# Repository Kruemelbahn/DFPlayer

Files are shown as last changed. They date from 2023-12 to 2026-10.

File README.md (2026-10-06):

# DFPlayer

DFPlayer is an ATmega328-board to control a soundmodul "DFPlayer - mini".<br>
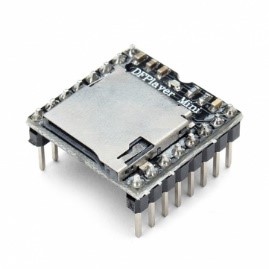
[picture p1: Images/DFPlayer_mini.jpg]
<br>

For more details please refer to the [manual](Documentation/AVRSound_DFPlayer.pdf).<br>

### Sound-FRED
There is also a hardware-version for a Sound-FRED available:<br>
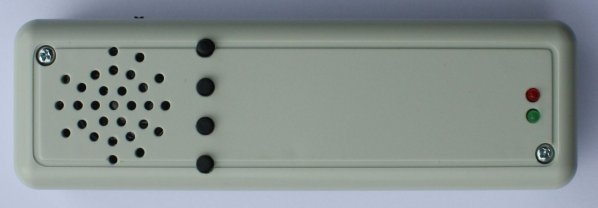
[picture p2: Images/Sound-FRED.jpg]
<br>
For compilation as Sound-FRED active/deactivate #defines in DFPlayer.ino and use this [boarddefinition](Boarddefinition%20for%20SoundFRED.txt).<br>

For more details please refer to the [manual](Documentation/AVRSound_DFPlayer-Sound-FRED.pdf).<br>

A battery tray for holding the battery can be found [here](https://github.com/Kruemelbahn/3D-Printables/blob/main/Geh%C3%A4use%20und%20Komponenten/Akkuschale-SoundFred.stl).

### Requested libraries
DFPlayer requires my libraries listed below in addition to various Arduino standard libraries:<br> 
- [HeartBeat](https://www.github.com/Kruemelbahn/HeartBeat)
- [OLEDPanel](https://www.github.com/Kruemelbahn/OLEDPanel)

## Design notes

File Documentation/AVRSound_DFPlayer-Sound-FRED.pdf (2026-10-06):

AVR-Sound – DFPlayer Sound-FRED | Version 22

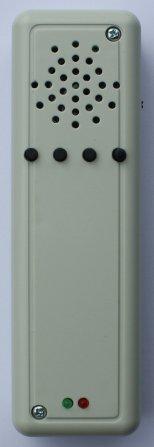
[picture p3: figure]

06.10.2026 | 1

Dipl.-Ing. Michael Zimmermann
Buchenstr. 15
42699 Solingen
- 0212 46267
- http://www.kruemelsoft.privat.t-online.de
- BwMichelstadt@t-online.de

### AVR-Sound – DFPlayer Sound-FRED

Hardware Version 2.0
Software Version 22

© 2017 – heute Michael Zimmermann

Wichtige Hinweise

Die hier beschriebenen elektrischen Schaltungen sind nur für den Einsatz auf Modelleisenbahnanlagen vorgesehen. Der Autor dieser Anleitung übernimmt keine Haftung für Aufbau und Funktion von diesen Schaltungen bei unsachgemäßer Verwendung sowie für beliebige Schäden, die aus oder in Folge Aufbau oder Betrieb dieser Schaltungen entstehen.

Für Hinweis auf Fehler oder Ergänzungen ist der Autor dankbar.

Ein Nachbau ist nur zum Eigenbedarf zulässig, die kommerzielle Nutzung Bedarf der schriftlichen Zustimmung des Autors.

## Inhalt

All Schematic and Board are licensed under a
Creative Commons Attribution-NonCommercial-ShareAlike 3.0 Unported License, see <http://creativecommons.org/licenses/by-nc-sa/3.0/legalcode>.

This program is free software: you can redistribute it and/or modify it under the terms of the GNU General Public License as published by the Free Software Foundation, either version 3 of the License, or (at your option) any later version.

This program is distributed in the hope that it will be useful, but WITHOUT ANY WARRANTY; without even the implied warranty of MERCHANTABILITY or FITNESS FOR A PARTICULAR PURPOSE. See the GNU General Public License for more details.

You should have received a copy of the GNU General Public License along with this program. If not, see <http://www.gnu.org/licenses/>.

### 1 Was ist das?

Mit dem AVR-Sound DFPlayer wurde ein Paket entwickelt, kostengünstig und einfach MP3-Sounds auf der Modellbahnanlage abzuspielen.

Bereits mit dem AVR-Sound DFPlayer war es möglich, einen Sound-FRED zu realisieren.

Für diesen hier beschriebenen Sound-FRED wurde die Hardware so angepasst, dass die neu entwickelte Platine in das bewährte Fred-Gehäuse passt:

- Es kommt das bewährte DFPlayer Mini MP3 Player Modul zum Einsatz

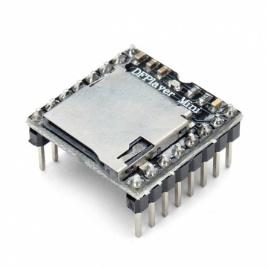
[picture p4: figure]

- Die Spannungsversorgung erfolgt über einen LiPo.
Dessen Aufladung erfolgt über ein 5V-(Handy-)Netzteil mit Mini-USB-Stecker.

Den originalen Sound-FRED gibt es hier:
http://www.h0fine.de

Mögliche Sounds findet man z.B. hier: http://kleinbahnwiki.de/index.php/Sounds#Deutschland_Eisenbahnger.C3.A4usche
… oder über eine Google-Suche – sofern man keine eigenen Sounds vorrätig hat.

Das Handbuch zum DFPlayer-Modul gibt es hier: http://www.dfrobot.com/image/data/DFR0299/DFPlayer%20Mini%20Manul.pdf

### 2 Konfiguration

2.1Anschluss und Einstellungen

Die Konfiguration beschränkt sich hier lediglich auf das Aufspielen der zu verwendenden Sounddateien auf einer Micro-SD-Karte.

### 2.1.1 Spannungsversorgung

Erfolgt über den eingebauten LiPo¹
, dieser kann über ein externes 5V-(Handy-) Netzteil an der USB-Mini-Buchse geladen werden.

Der Sound-FRED wird über den Schiebeschalter ein- und ausgeschaltet.

### 2.1.2 Anzeige-LEDs

Bei angeschlossenem Netzteil wird der Ladezustand des Lipo über zwei LEDs angezeigt:
- Rot = im Lademodus / der LiPo muss weiter geladen werden
- Grün = Ladevorgang beendet / LiPo geladen

### 2.1.3 Start eines Sounds

…erfolgt nach dem Einschalten über den Schiebeschalter mit
- einen der vier Taster.

Jedem Taster ist ein Sound zugeordnet, der Sound wird einmalig abgespielt, ein (vorzeitiges) Stoppen des Sounds ist nicht möglich.

Grundsätzlich gilt: Alle Sound-Dateien befinden sich auf der Micro-SD-Karte des DFPlayer Mini MP3 Player Modul (FAT 16 oder FAT32, max. 32GB) im Unterordner mp3:

und haben die Namen xxxx.mp3. Hierbei steht xxxx für die Angabe der Sound-Nummer von 0001 bis 0004:

### 2.1.4 Festlegung der Lautstärke des abzuspielenden Sounds

…erfolgt über
- das Potentiometer auf der Platine unterhalb des Schiebeschalters

1 Abkürzung für Lithium-Polymer-Akkumulatoren

2.2Übersicht und Beschreibung der vorhandenen CVs

Es können nur CV1, 7 und 17 geändert werden.

CV | Bedeutung
1 | Eindeutige Identifikationsnummer 1…126, Standard = 1
2 | Abzuspielende Sound-Nummer 1…255, Standard = 1 Kann nicht geändert werden.
3 | Lautstärke 1…30, Standard = 30 Kann nicht geändert werden.
4 | Abspielmodus für den Sound, Standard = 4: 4 = „Sound-FRED“: Sound wird einmal abgespielt, unabhängig von der Schaltdauer an einem der Taster Kann nicht geändert werden.
5 | Anschluss invertieren, Standard = 01000000 Kann nicht geändert werden.
6 | Anschluss nicht verwendet, Standard = 00110011 Kann nicht geändert werden.
7 | Softwareversion, (eigentlich) nur lesbar: Wird hier der Wert 0 eingetragen, so werden alle CVs auf ihren Standardwert zurückgesetzt.
8 | 5 = Kennung „AVR-Sound-FRED“, nur lesbar Kann nicht geändert werden.
9 | Allgemeine Konfigurationen 1, Standard = 00000000 Kann nicht geändert werden.
10 | Schaltschwelle an Analog von Lautsprecher, unterhalb derer Sound aus sofort wirkt, 0…255, Standard = 0 = keine Schaltschwelle (Sound aus sofort wirkt direkt). Kann nicht geändert werden.
11 | Betriebsart für den Schaltausgang, Standard = 0 Kann nicht geändert werden.
12 | Einschaltverzögerung (in 0,1s) für Schaltausgang, 0…255, Standard = 0 = keine Zeitverzögerung Kann nicht geändert werden.
13 | Dauer (in 0,1s) für Schaltausgang, 0…255, Standard = 0 = Dauerimpuls an Schaltausgang Kann nicht geändert werden.
14 | Pause (in 0,1s) zwischen dem wiederholten Abspielen des Sounds, Standard = 0 = keine Pause zwischen zwei Sounds Kann nicht geändert werden.
15 | Schaltschwelle an Analog von Lautsprecher, über der Schaltausgang eingeschaltet wird, 0…255, Standard = 0 Kann nicht geändert werden.
16 | Schaltschwelle an Analog von Lautsprecher, unter der Schaltausgang ausgeschaltet wird, 0…255, Standard = 9 Kann nicht geändert werden.
17 | LocoNET®-Konfiguration: Bit 0 = 0 = Kein LocoNET®-Interface an K4 angeschlossen 1 = Verwende LocoNET®-Interface an K4 (wenn vorhanden) Alle anderen Bits werden nicht verwendet und können nicht geändert werden. Standard = 00000000 (=0)

18 | LocoNET®-Adresse für Sound ein bzw. Sound aus, 0…2048, Standard = 0 Kann nicht geändert werden.
19 | Maximale Anzahl der verwendeten LocoNET®-Adressen für Sound ein bzw. Sound aus, Standard = 1 Kann nicht geändert werden.
20 | Pause (in s) zwischen dem erneuten Abspielen des Sounds, wenn CV4 = 0 ist, Standard = 0 = keine Pause zwischen zwei Sounds Kann nicht geändert werden.
21 | Entprellzeit (in 10ms) für den Eingang Sound ein. Standard = 2 (20ms) Kann nicht geändert werden.
22 | LocoNET®-Adresse für Schaltausgang ein bzw. Schaltausgang aus, 0…2048, Standard = 0 Kann nicht geändert werden.
23 | Ausschaltverzögerung (in 0,1s) für Schaltausgang, 0…255, Standard = 0 = keine Zeitverzögerung Kann nicht geändert werden.
24 | Schaltausgang wird bei den freigegebenen Sounds aktiviert (wenn CV9 Bit 6 gesetzt) Kann nicht geändert werden.
25 | Abzuspielende Sound-Nummer, wenn der Sound gestoppt wird 0…255, Standard = 0 = kein Sound Kann nicht geändert werden.

### 3 Hardware

Das entsprechende Schaltbild ist – ebenso wie die Stücklisten - im Anhang zu finden.
Die Platinen sind professionell gefertigt und haben einen beidseitigen Bestückungsaufdruck, auf Bestückungspläne und –anleitung wird daher in dieser Anleitung verzichtet.
Viele Bauteile sind in der SMD-Variante verbaut, um den Aufbau kompakt gestalten zu können. SMD-Bauteile sind in der Stückliste farbig hervorgehoben.
Praxis für das Löten von SMD-Bauteilen sollte vorhanden sein.
Das eigentliche DFPlayer-Modul gibt es z.B. bei Amazon.

### 4 Software

Der Prozessor benötigt eine Software, um seine Aufgabe zu erfüllen.
Die Software wurde mit der Entwicklungsumgebung für die frei verfügbare Arduino-IDE (http://www.arduino.cc/) erstellt.
Die Kompilierung erfolgt für das Board „Arduino UNO 8Mhz²
“, für den AVR-Sound-FRED muss zudem in der Datei DFPlayer.ino das
#define _SPECIAL_SOUND_FRED_

aktiviert werden da die Taktfrequenz des Prozessors nicht 16MHz sondern 8MHz beträgt.
Die gesamte Software ist gemäß der zugehörigen Lizenz verfügbar.

2 Hier gibt es die Boarddefinitionsdatei: https://github.com/Kruemelbahn/DFPlayer/blob/main/Boarddefinition%20for%20SoundFRED.txt

4.1HEX-Dateien

Im | GitHub-Repository | befinden | sich | im | Ordner | „Hexfiles“
(https://github.com/Kruemelbahn/DFPlayer/tree/main/Hexfiles) die bereits mit dem Quellcode
kompilierten | HEX-Dateien. | Diese | Hex-Dateien | können | mit | einem | AVR-
Programmiergerät auf den Prozessor geladen werden (siehe „Den AVR flashen“). Die Namensgebung der Dateien bezeichnet die Ausbaustufe der Software:
- „SoundFred“: kennzeichnet die Verwendung für den SoundFred

4.2Quellcode

Der Quellcode im Hauptverzeichnis (https://github.com/Kruemelbahn/DFPlayer) ist genau wie meine zugehörigen Bibliotheken unter GitHub verfügbar.
Der Quellcode wird nur benötigt, wenn
- Man neugierig ist
- Oder den Quellcode ändern und somit neu kompilieren möchte. Zum Kompilieren wird die aktuelle Arduino-IDE benötigt.

Die Kompilierung erfolgt für das Board „Arduino UNO“.
Für eine erfolgreiche Kompilierung sind nachfolgende Arduino-Bibliotheken erforderlich:
Arduino-Library | | | (Link)
Adafruit-GFX-Library_master | https://github.com/adafruit/Adafruit-GFX-Library
Adafruit_LED_Backpack_Library_master | https://github.com/adafruit/Adafruit_LED_Backpack
Adafruit_RGB_LCD_Shield_Library_master https://github.com/adafruit/Adafruit-RGB-LCD-Shield-Library
Bounce | http://www.arduino.cc/playground/Code/Bounce
Bounce2mcp | https://github.com/cosmikwolf/Bounce2mcp
DFPlayer-Mini-mp3-master | https://wiki.dfrobot.com/DFPlayer_Mini_SKU_DFR0299
LocoNET® | http://mrrwa.org/loconet-interface/
MemoryFree | http://www.arduino.cc/playground/Code/AvailableMemory
HeartBeat
LCDPanel | erfordert: Adafruit-GFX-Library
(Bibliotheken, die grün hinterlegt sind, stehen in meinem Github (http://www.github.com/Kruemelbahn) zur Verfügung.)

4.3Den AVR flashen

Hierzu kann jeder AVR-Brenner verwendet werden, der diesen Prozessor unterstützt; meine Prozessoren brenne ich mit AVRDude und USB AVR Prog von U.Radig (http://www.ulrichradig.de/).
Die Fuses sind wie folgt zu setzen: lfuse = 0xFF; hfuse = 0xDE; efuse = 0xFD

4.4Versionsgeschichte

V15 | 02.10.2021 | entspricht der AVR-DFPlayer-Software
V16 | 28.06.2022 | die nachfolgenden Verbesserungen sind nicht für den AVR-Sound-FRED
| | verfügbar und werden hier nur zu Dokumentationszwecken gelistet:
| | neu: CV20 zur Begrenzung der LocoNET®-Adressen
| | CV23 und CV24, um den Schaltausgang unabhängig über LocoNET® steuern
| | zu können
| | neu: CV25 Ausschaltverzögerung für den Schaltausgang
| | neu: CV26 Verknüpfung von Sound-Nummer mit Schaltausgang
| | neu: CV11 mit Betriebsart=3
V17 | 24.08.2022 | CV-Editor optimiert, CVs neu organisiert (in der Versionsgeschichte vor V17
| | benannte CVs haben sich teilweise verschoben)
V18 | 01.10.2022 | neu: CV9 Bit7 und CV25
V19 | 21.09.2023 | geänderte Bedeutung für CV9 Bit 7
V20 | 23.10.2023 | Korrektur für FastClock-Telegramme, die von JMRI gesendet werden
| 09.12.2023 | Kapitel 4 „Software“ aktualisiert
V21 | 21.12.2023 | FastClock-Telegrammauswertung optimiert
| 03.12.2024 | Angabe zu Fuses hinzugefügt
| 04.12.2024 | Kapitel 4 „Software“ überarbeitet
V22 | 06.10.2026 | CV8: Anzeige auch von MANUFACTURER- und DEVELOPER-ID,
| | JMRI-Datei angepasst

### 5 Anhang

5.1Schaltplan AVR-Sound-FRED

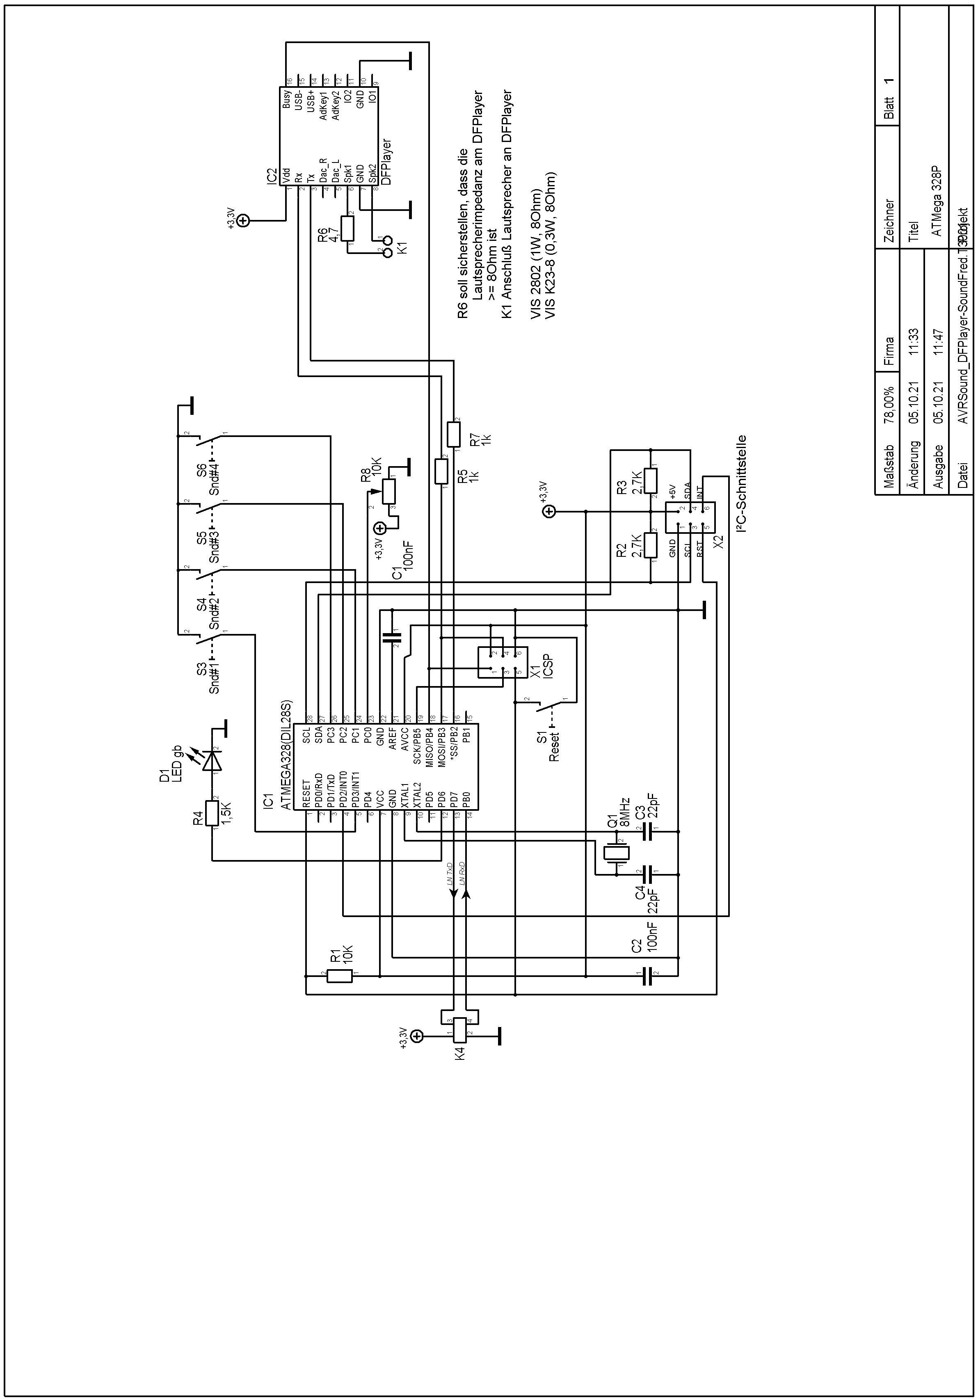
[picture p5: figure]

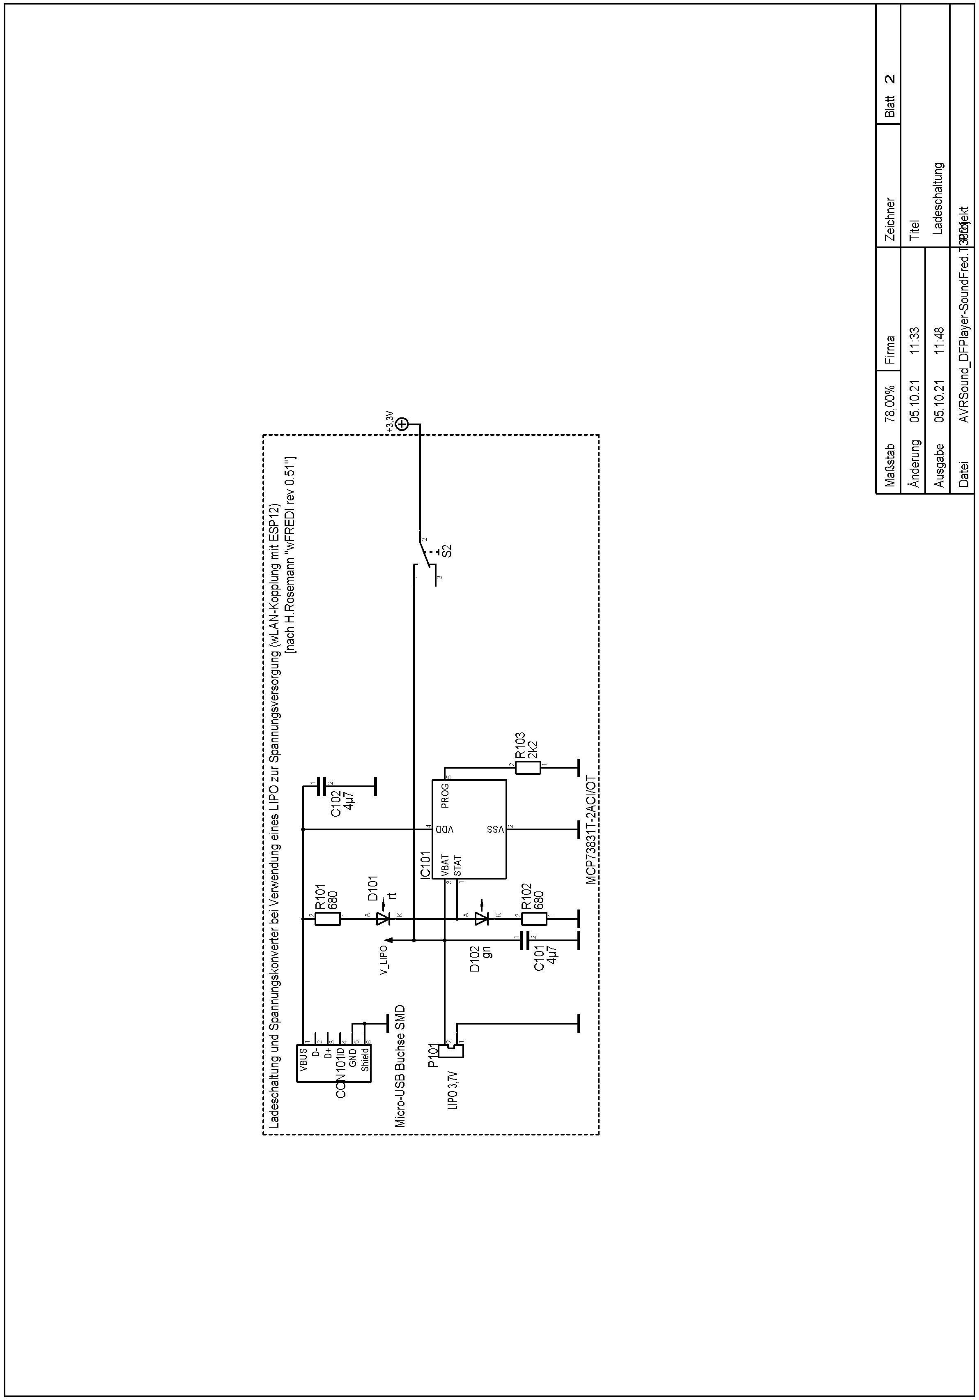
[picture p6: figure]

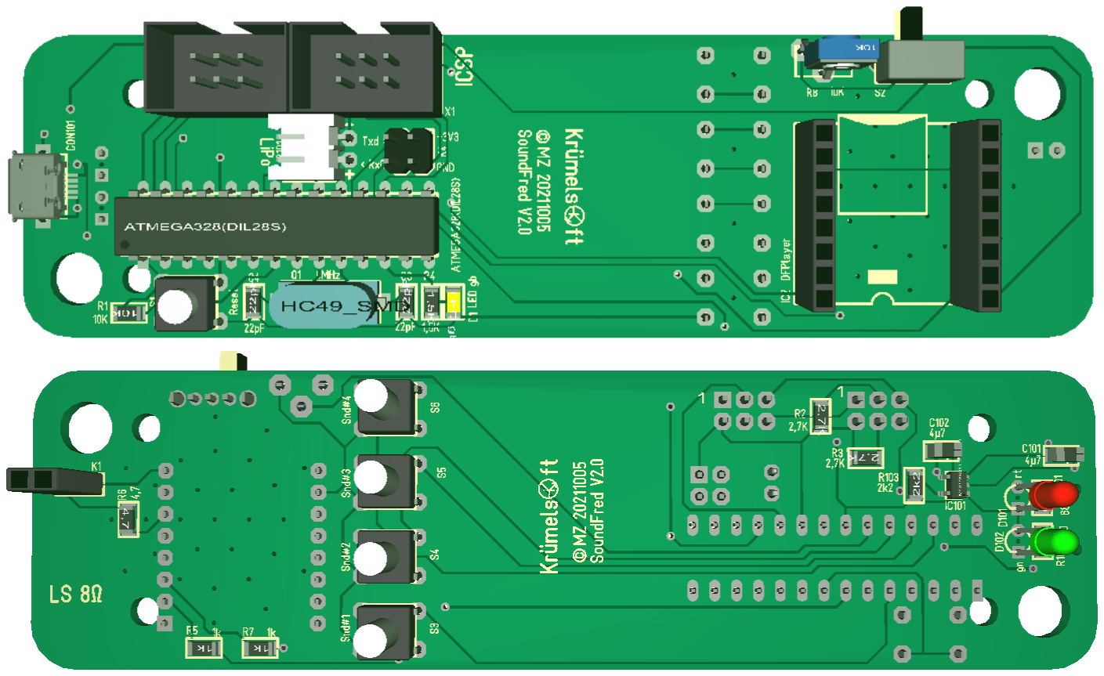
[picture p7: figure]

### 5.1.1 Stückliste AVR-Sound-FRED

3 Die in der Stückliste genannten Bestellnummern können aktuell geändert worden bzw. der Artikel nicht mehr lieferbar sein.
4 Typ der Micro-SD-Karte nach Wunsch, es ist die Spezifikation durch den DFPlayer zu beachten.
Anzahl | Bauteil | Bestellnummer (Reichelt³ ) | Anmerkung
| | | Platine 124mm * 35mm, doppelseitig, V2.0
2 | C1, C2 | X7R-G1206 100N
2 | C3, C4 | NPO-G1206 22P
2 | C101, C102 | KEM X5R1206 4,7U
1 | D1 | SMD-LED 1206 GE
1 | D101 | LED 3MM 2MA RT
1 | D102 | LED 3MM 2MA GN
2 | D101, D102 | FIS MAH 304 | Abstandshalter für die einfache LED-Montage
1 | IC1 | ATMEGA 328P-PU
1 | IC1 | GS 28P-S
1 | IC2 | --- | DFPlayer Mp3-Soundmodul Montage ggf. auch über zwei Buchsenleisten BL 1X10G 2,54
1 | IC2 | INTENSO MSDHC4G | Micro-SD-Karte⁴ für DFPlayer
1 | IC101 | MCP 73831T-2ACI
1 | CON101 | MIC USB BBU
1 | K1 | SL 1X10G 2,54 | Es werden 2 Stifte benötigt
1 | K1 | BL 1X10G 2,54 | Es werden zwei Buchsen benötigt
1 | K4 | SL 2X10G 2,54 | Es werden 2x2 Stifte benötigt
1 | P101 | JST XH2P ST90
1 | Q1 | 8,0000-HC49-SMD
1 | R1 | SMD 1/4W 10K

### 5.1.2 Lipo-Empfehlungen

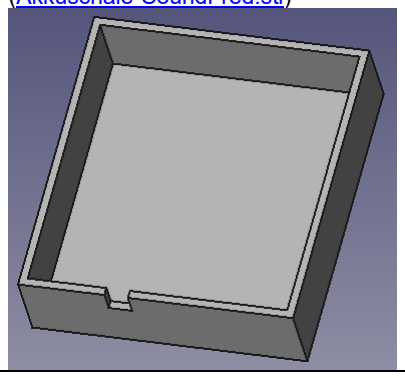
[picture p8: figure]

Exp-tech.de: EXP-T11-004 (30x30x5mm, 400mAh) https://www.exp-tech.de/zubehoer/batterien-akkus/lipo-akkus/5800/3.7v-400mah-lithium-polymer-akku-mit-jst-ph-anschluss (https://www.exp-tech.de/zubehoer/batterien-akkus/lipo-akkus/5800/3.7v-400mah-lithium-polymer-akku-mit-jst-ph-anschluss)

Eremit.de: EREMIT 3.7V 1000mAh LiPo Akku 903040 (30x40x9, 1000mAh) https://www.eremit.de/p/eremit-3-7v-1000mah-lipo-akku-903040

Der LiPo wird auf der TOP-Seite zwischen IC1 (Atmega 328) und IC2 (DFPlayer) platziert.

5 Eigentlich tut es jeder Lautsprecher, der ins Gehäuse passt (maximale Höhe ca. 4mm).
Weiterhin ist darauf zu achten, dass die Impedanz >= 8 Ω ist: hierzu ist ggf. R6 zur Anpassung zu verwenden.
2 | R2, R3 | SMD 1/4W 2,7K
1 | R4 | SMD 1/4W 1,5K
2 | R5, R7 | SMD 1/4W 1,0K
1 | R6 | SMD 1/4W 0,0 | wenn Lautsprecherimpedanz < 8Ω ist, dann ist ein passender SMD-Widerstand zu verwenden!
1 | R8 | ACP 6-S 10K | Poti für die Lautstärkeeinstellung
2 | R101, R102 | SMD 1/4W 680
1 | R103 | SMD 1/4W 2,2K
1 | LS | VIS K23-8 | Lautsprecher⁵ , 8Ω, Ø 20 mm
1 | S1 | TASTER 3301
1 | S2 | | Mouser: 611-102011MA1QN1
4 | S3, S4, S5, S6 | TASTER 3301B
2 | X1, X2 | WSL 6G
1 | | SP 2090 SW | FRED-Gehäuse, (in grau bei Conrad = Bestell-Nr.: 541214 - 62)
1 | | SBL 29065-100 | Blechschrauben 2,9mm x 6,5mm für die Platinenbefestigung Packung enthält 100 Stück, benötigt werden 2 Stück
1 | LiPo 3,7V | | Maximale Baugröße ca. 40*30*10mm
1 | | | LiPo-Liegesschale, passend z.B. für EXP-T11-004 (s.u.) (Akkuschale-SoundFred.stl) (https://github.com/Kruemelbahn/3D-Printables/blob/main/Geh%C3%A4use%20und%20Komponenten/Akkuschale-SoundFred.stl)

### 5.1.3 Hinweis zur Platine

Die professionell gefertigte Platine hat
- einen beidseitigen Bestückungsdruck zur Erleichterung der Bestückung
- und Markierungsbohrungen (Ø 0,5mm), mit dem die im Gehäuse notwendigen Bohrungen markiert werden können:
- für die zwei Leuchtdioden
- für die vier Taster
- und für Bohrungen für den Lautsprecher (Schallaustritt) Die Platine wird unbestückt in das Unterteil des Gehäuses (das ist das, wo die vier Gehäuseschrauben befestigt werden!) gelegt und mit zwei Blechschrauben befestigt:

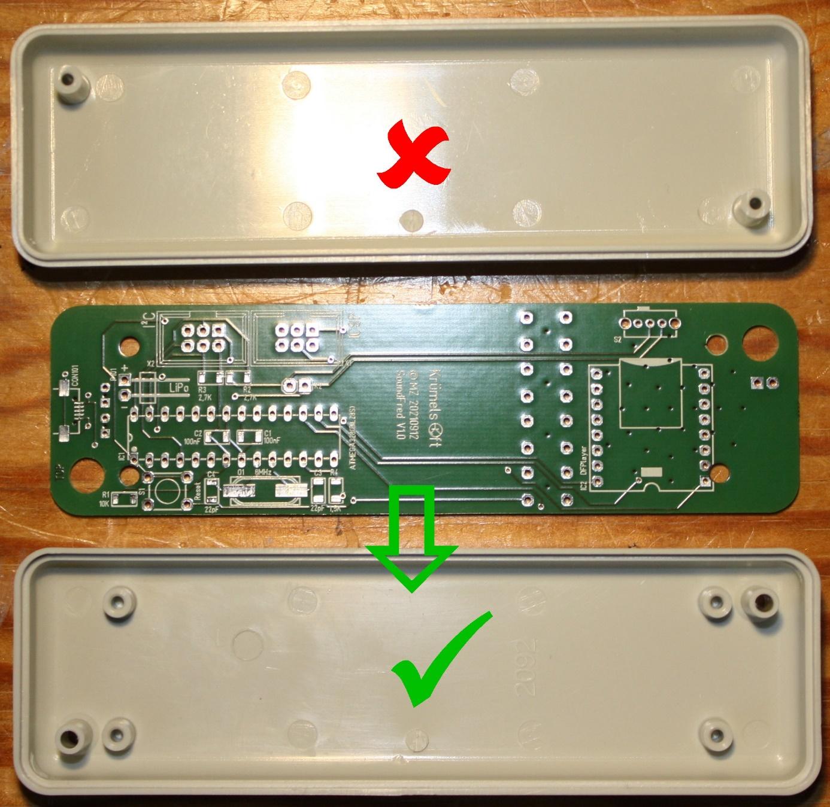
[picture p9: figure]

Mit einem Bohrer (Ø 0,5mm) werden diese Löcher (rote und violette Kreise) im Gehäuse markiert:

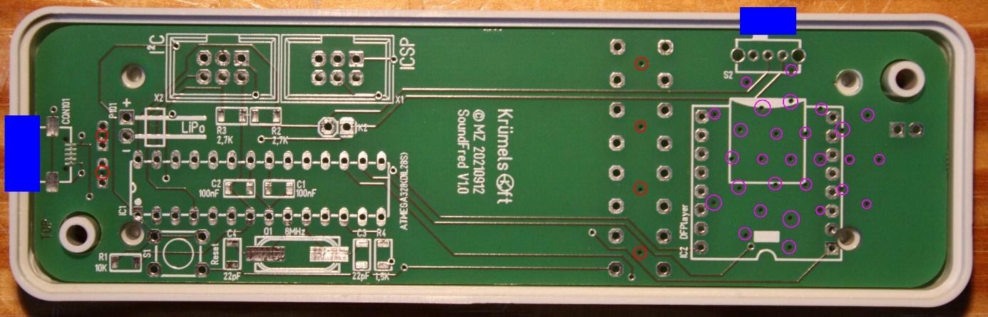
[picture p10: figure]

Dazu einen Bohrer (Ø 0,5mm) in einen Stiftenkloben spannen, durch die Löcher führen und leicht drehen als wolle man das Loch von Hand bohren. Dies erzeugt einen Markierungspunkt wie von einer Reißnadel.
Die roten Löcher
- links sind für die zwei Leuchtdioden
- in der Mitte rechts für die vier Taster
Die violetten Löcher (28) markieren Bohrungen für den Lautsprecher (Schallaustritt).

Nach dem Markieren können die Bohrungen eingebracht werden:
LEDs | Ø 3 mm
Taster | Ø 4 mm
Lautsprecherbohrungen | Ø 2 mm

Weiterhin sind zwei Aussparungen (blau) im Gehäuse anzubringen:
- links für die USB-Buchse
- oben für den Ein-Aus-Schalter

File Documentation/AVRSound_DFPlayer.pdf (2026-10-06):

AVR-Sound – DFPlayer | Version 22
06.10.2026 | 1

Dipl.-Ing. Michael Zimmermann
Buchenstr. 15
42699 Solingen
- 0212 46267
- http://www.kruemelsoft.privat.t-online.de
- BwMichelstadt@t-online.de

### AVR-Sound - DFPlayer

Hardware Version 1.1
Software Version 22

© 2017 – heute Michael Zimmermann

Wichtige Hinweise

Die hier beschriebenen elektrischen Schaltungen sind nur für den Einsatz auf Modelleisenbahnanlagen vorgesehen. Der Autor dieser Anleitung übernimmt keine Haftung für Aufbau und Funktion von diesen Schaltungen bei unsachgemäßer Verwendung sowie für beliebige Schäden, die aus oder in Folge Aufbau oder Betrieb dieser Schaltungen entstehen.

Für Hinweis auf Fehler oder Ergänzungen ist der Autor dankbar.

Ein Nachbau ist nur zum Eigenbedarf zulässig, die kommerzielle Nutzung Bedarf der schriftlichen Zustimmung des Autors.

## Inhalt

2.1.11 | Vom LocoNET®
5.5 | Sound einfach über LocoNET®
7.2 | LocoNET®
7.2.1 | Stückliste LocoNET®

7.9 Kommunikation: LocoNET®

All Schematic and Board are licensed under a
Creative Commons Attribution-NonCommercial-ShareAlike 3.0 Unported License, see <http://creativecommons.org/licenses/by-nc-sa/3.0/legalcode>.

This program is free software: you can redistribute it and/or modify it under the terms of the GNU General Public License as published by the Free Software Foundation, either version 3 of the License, or (at your option) any later version.

This program is distributed in the hope that it will be useful, but WITHOUT ANY WARRANTY; without even the implied warranty of MERCHANTABILITY or FITNESS FOR A PARTICULAR PURPOSE. See the GNU General Public License for more details.

You should have received a copy of the GNU General Public License along with this program. If not, see <http://www.gnu.org/licenses/>.

### 1 Was ist das?

AVR-Sound DFPlayer ist der Versuch, kostengünstig und einfach MP3-Sounds auf der Modellbahnanlage abzuspielen.
Nachdem kommerzielle Geräte sehr teuer sind, blieb nur der Selbstbau - zudem so auch eigene Anforderungen umgesetzt werden konnten:
- in meinem Stellwerk verwendbar
- an meiner Kanalbrücke verwendbar
- für meine Feuerwehr verwendbar
- über LocoNET® ansteuerbar
- erweiterungsfähig – bei neuen Ideen und Anforderungen

Zur Anwendung kommt ein ATMEL ATMEGA 328 (als Entwicklungsumgebung wurde ein Arduino UNO R3 SMD verwendet), der ein entsprechendes Sound-Modul (hier: DFPlayer Mini MP3 Player Modul) ansteuert.


Nun ist das DFPlayer-Modul an sich schon flexibel und kann direkt über Tasten angesteuert werden. Eine Ansteuerung über den ATMEL-Prozessor steigert die Möglichkeiten, einige Funktionen sind durch den Prozessor überhaupt erst möglich. Weiterhin hat das DFPlayer-Modul einen Slot für Micro-SD-Karten, auf denen die einzelnen Sounds gespeichert sind (ohne SD-Karte kein Sound!). Bei einem Wechsel der Sounds wird lediglich der Inhalt der Micro-SD-Karte geändert, eine Softwareänderung für den Prozessor ist nicht erforderlich.

Für den Betrieb von AVR-Sound wird eine leistungsfähige 5V-Versorgung benötigt, als Steueranschlüsse stehen u.a. zur Verfügung:

- Sound ein
- Sound aus (zwei separate Eingänge)
- Schaltausgang (auch für höhere Lasten mit MOSFET-Schaltstufe)

Das Hauptaugenmerk bei der Entwicklung lag bei der einfachen Verwendung für meine Module.
Die vielfältigen Konfigurationsmöglichkeiten (siehe CVs) erlauben insgesamt ein breites Anwendungsspektrum.

Weiterhin kann über den I²C-Anschluss von AVR-Sound auch ein FastClockSlave-Modul (Kapitel 7.5: FastClock (Nebenuhr)) angeschlossen werden.

Startpunkt der Entwicklung war übrigens ein Bauvorschlag als Licht- und Soundmodul für ein Gewitter: http://www.trainelectronics.com/Animation-thunder-lightning/ -und das ist dann gewachsen…

…und beim Entwurf des LocoNET®-Interfaces hat LocoIO von Hans deLoof (http://users.telenet.be/deloof/pageDE8.html) Pate gestanden:
→ AVR-Sound kann mit LocoIO über das LocoNET® angesteuert werden.

### 2 Konfiguration

2.1Anschluss und Einstellungen

PXy bezeichnet den Portanschluss am ATMEGA 328, [] bezeichnen den Port am Arduino UNO.

### 2.1.1 Spannungsversorgung

AVR-Sound benötigt eine 5V-Versorgung (mit entsprechender Leistung für das DFPlayer-Modul):
- +5V an K5.4 / K4.7 / X4.7
- Masse (0V, GND) an K5.3 / K4.3 / X4.3

Jumper für die Spannungsversorgung
- J2 ist zu öffnen, wenn das DFPlayer-Modul mit 3,3V anstelle von 5V versorgt werden soll (dann muss auch IC3, C5 und C6 bestückt werden)
- Soll das DFPlayer-Modul mit einer separaten 5V-Versorgung betrieben werden, so ist J6 zu öffnen. Der Anschluss der separaten Versorgung erfolgt dann ebenfalls über J6
- mit J1 kann die Spannung für einen NF-Verstärker (Anschluss an K3) ausgewählt werden (+5V oder +12V)

### 2.1.2 Steueranschlüsse - allgemeine Informationen

- Die Steueranschlüsse für Sound ein bzw. Sound aus können wahlweise gegen +5V schalten (1-aktiv) oder gegen Masse schalten (0-aktiv), die entsprechende Einstellung erfolgt über CV5.
- Die Eingänge am PortExpander sind nicht konfigurierbar und immer 0-aktiv.
- Für alle 0-aktiven Eingänge wird der jeweils zugehörige Pull-Up-Widerstand aktiviert.
- Nicht verwendete Anschlüsse werden über CV6 definiert.
- Über S2 kann wahlweise
- die Sound-Nummer (CV9 Bit 0 = 1) oder
- die Lautstärke (CV9 Bit 1 = 1)
gewählt werden.

### 2.1.3 Anzeige-LEDs

Auf dem AVR-Soundmodul gibt es zwei Anzeige-LEDs:
- D3 neben dem Reset-Taster zur Anzeige des Schaltausgangs
- D1 neben dem Quarz, der „Herzschlag“ zur Anzeige des ordnungsgemäßen Programmlaufs.
Schnelles | Blinken | (2Hz) | dieser | LED | zeigt | eine | Störung | an.
Bei konstantem (Dauer-)Licht arbeitet das Programm nicht mehr, dann kann ein Reset helfen.

### 2.1.4 Signale und deren Anschlüsse

- Sound ein (K5.1 / K4.4 / PD4[4])
- Sound aus (K5.2 / K4.6 / X4.6 / PD5[5])
- Sound aus 2 (K4.8 / X4.8 / PB0[8])
nur nutzbar, wenn kein LocoNET®-Interface aktiviert ist
- Schaltausgang (X4.4 / PB1[9])
- DFPlayer aktiv (“busy”, PB4[12])
- Soundmodul aktiv (PB5[13], Anschluss über X1 (ICSP-Stecker))

- Analog von Lautsprecher (PC0[14], J3 ist zu schließen)

### 2.1.5 Start eines Sounds

…erfolgt über
- den Anschluss Sound ein oder
- einen LocoNET®-Befehl oder
- über den PortExpander Eingang 1…16 bzw. 17…32 oder
- einen der vier Taster (anstelle von S2; siehe „Sound-FRED“)

### 2.1.6 Stopp eines Sounds

…erfolgt über
- Sound aus oder
- Sound aus 2 (nicht bei Verwendung des LocoNET®-Interface) oder
- einen LocoNET®-Befehl
Über CV9 Bit 3 kann festgelegt werden, ob der Anschluss Sound aus den Sound sofort (Sound aus sofort) oder erst nach dem kompletten Abspielen stoppt (Sound aus).
- CV10
legt fest, ob und unterhalb welcher Schaltschwelle der Befehl Sound aus sofort wirkt. Dazu ist auch J3 zu schließen.
- CV25
legt fest, ob beim Stopp des Sounds ein Sound abgespielt werden soll. Hierzu muss CV9 Bit 4 gesetzt sein.

### 2.1.7 Festlegung der abzuspielenden Sound-Nummer

…wird festgelegt über
- CV2
- CV9 Bit 0
- CV25
bzw. über die Anwahl mittels PortExpander (CV9 Bit 2).

Ist CV17 Bit 1 gesetzt, wird die abzuspielende Sound-Nummer aus der Adresse des empfangenen LocoNET®-Telegrammes genommen.

Grundsätzlich gilt: Alle Sound-Dateien befinden sich auf der SD-Karte des DFPlayer Mini MP3 Player Modul (FAT 16 oder FAT32, max. 32GB) im Unterordner mp3:

und haben die Namen xxxx.mp3. Hierbei steht xxxx für die Angabe der Sound-Nummer von 0001 bis 0255:

### 2.1.8 Festlegung der Lautstärke des abzuspielenden Sounds

…erfolgt über
- CV3
- CV9 Bit 1

### 2.1.9 Festlegung des Abspielmodus des abzuspielenden Sounds

…wird definiert in
- CV4
- CV9 Bit 7
- CV14
- CV20

### 2.1.10 Vom Schaltausgang verwendete CVs

Das Verhalten des Schaltausgang wird gesteuert durch
- CV5 Bit 5
- CV6 Bit 5
- CV9 Bit 5
- CV9 Bit 6
- CV11
- CV12
- CV13
- CV22
- CV23
- CV24

Wenn CV6 Bit 7 nicht gesetzt ist und J3 geschlossen wird, kann der Schaltausgang pegelabhängig mit
- CV15
- CV16
geschaltet werden.
CV11, CV12 und CV23 bleiben unberücksichtigt, wenn der Schaltausgang über LocoNET® geschaltet wird.
CV23 und CV24 werden bei Verwendung des LocoNET®-Interfaces berücksichtigt. Wird der Schaltausgang über das LocoNET® angesteuert, wirkt das wie eine ODER-Verknüpfung zum über CV11 vorgegebenen Verhalten.
Wenn CV9 Bit 6 gesetzt ist, wird der Schaltausgang nur aktiviert, wenn der entsprechende Sound in CV24 freigegeben ist.

### 2.1.11 Vom LocoNET®

-Interface verwendete CVs
Das LocoNET®-Interface verwendet
- CV11
- CV17 Bit 0
- CV17 Bit 1
- CV18
- CV19
- CV22
Bei Verwendung des LocoNET®-Interface ist J4 zu schließen.
Der Eingang Sound aus 2 (K4.8 / X4.8 / PB0[8]) kann nicht verwendet werden.

### 2.1.12 Vom PortExpander verwendete CVs

Der PortExpander verwendet
- CV9 Bit 2

### 2.1.13 Von FastClock verwendete CVs

FastClock verwendet:
- CV17 Bit 2
- CV17 Bit 3
- CV17 Bit 5
Weiterhin ist das LocoNET®-Interface anzuschließen und über
- CV17 Bit 0
zu aktivieren und J4 zu schließen.

2.2Übersicht und Beschreibung der vorhandenen CVs

Für alle CVs gilt:
CVs werden bei Erst-IBN eingestellt und sollten danach nicht mehr geändert werden.
CV | Bedeutung
1 | Eindeutige Identifikationsnummer 1…126, Standard = 1
2 | Abzuspielende Sound-Nummer 1…255, Standard = 1
3 | Lautstärke 1…30, Standard = 30
4 | Abspielmodus für den Sound, Standard = 0: Sound ein (K5.1 / K4.4 bzw. über PortExpander oder über LocoNET®) 0 = Sound wird einmal abgespielt, unabhängig von der Schaltdauer an Sound ein 1 = Sound wird (wiederholt) mit Pause (CV14) abgespielt, solange Sound ein eingeschaltet ist (Sound wird immer komplett abgespielt) 2 = Sound wird (wiederholt) mit Pause (CV14) abgespielt, solange Sound ein eingeschaltet ist (Sound wird sofort abgeschaltet) 3 = Sound wird (wiederholt) mit Pause (CV14) abgespielt und mit Sound aus bzw. Sound aus 2 ausgeschaltet (Sound wird immer komplett abgespielt) 4 = „Sound-FRED“: Sound wird einmal abgespielt, unabhängig von der Schaltdauer an einem der Taster der anstelle von S2 angeschlossen ist (ab SW-Version 3)
5 | Anschluss invertieren: (Bit nicht gesetzt: Signal ist 1-Aktiv¹ , Bit gesetzt: Signal ist 0-Aktiv¹ , für 0-Aktive Eingänge wird ein interner Pull-Up-Widerstand aktiviert) Bit 0 = Sound ein Bit 1 = Sound aus Bit 2 = ---Bit 3 = ---Bit 4 = Sound aus 2² Bit 5 = Schaltausgang (Eine Invertierung ist nicht sinnvoll, wenn die MOSFET-Schaltstufe verwendet wird!) Bit 6 = DFPlayer aktiv Bit 7 = ---Standard = 01010011
6 | Anschluss nicht verwendet: Bit 0 = Sound ein³ Bit 1 = Sound aus³ Bit 2 = ---Bit 3 = ---Bit 4 = Sound aus 2² ³ Bit 5 = Schaltausgang Bit 6 = ---Bit 7 = Analog von Lautsprecher (wenn das Bit nicht gesetzt ist, dann ist J3 zu schließen) Standard = 10000000

1 1-Aktiv: Schalter/Kontakt schaltet nach +5V, Eingang reagiert, wenn Spannung +5V
0-aktiv: Schalter/Kontakt schaltet nach GND, Eingang reagiert, wenn Spannung 0V
2 Ohne Bedeutung, wenn ein LocoNET®-Interface angeschlossen und verwendet wird.
3 Wird im „Schrankenmodus“ (Kapitel 5.2: Sound für den Bahnübergang (‚Schrankenmodus‘)) nicht berücksichtigt

7 | Softwareversion, (eigentlich) nur lesbar: Wird hier der Wert 0 eingetragen, so werden alle CVs auf ihren Standardwert zurückgesetzt. Anschließend sind alle CVs auf den gewünschten Wert zu setzen (=neue Inbetriebnahme erforderlich!)
8 | 5 = Kennung „AVR-Sound - DFPlayer“, nur lesbar Kann nicht geändert werden.
9 | Allgemeine Konfigurationen 1: Bit 0 = 0 = Verwende Sound-Nummer aus CV2 (1…255) 1 = Verwende Sound-Nummer von S2 (1…16) Ist Bit 1 gesetzt, bleibt Bit 0 unberücksichtigt, d.h. Bit 1 hat gegenüber Bit 0 die höhere Priorität bei der Verwendung von S2. Bei Verwendung eines PortExpanders bleibt Bit 0 immer unberücksichtigt, d.h. die Soundauswahl erfolgt dann immer über den PortExpander. Bit 1 = 0 = Verwende Lautstärke aus CV3 (1…30) 1 = Verwende Lautstärke von S2 Ist Bit 1 gesetzt, bleibt Bit 0 unberücksichtigt, d.h. Bit 1 hat gegenüber Bit 0 die höhere Priorität bei der Verwendung von S2. Bit 2 = 0 = Kein PortExpander am I²C-Bus angeschlossen 1 = Verwende PortExpander (wenn vorhanden) Die Soundanwahl über den PortExpander (Eingänge haben interne Pull-Up und sind 0-Aktiv) startet den gewählten Sound (1…16 (32), entsprechend dem betätigten Eingang [Eingang 1 = Sound 1, Eingang 2 = Sound 2 usw.]), sofort und spielt diesen ab. Bei mehreren betätigten Eingängen wird der höchste betätigte Eingang verwendet. Eine Änderung von Bit 2 wird erst nach einem Reset wirksam!
| Ist CV4 = 4 („Sound-FRED“) bleiben Bit 0,1 und 2 unberücksichtigt! Bit 3 = 0 = Sound aus wirkt als Sound aus 1 = Sound aus wirkt als Sound aus sofort Bit 4 = 0 = Eingang Sound ein bzw. Sound aus ohne Entprellung 1 = Eingang Sound ein bzw. Sound aus mit Entprellung Die Entprellzeit wird über CV21 festgelegt. Bit 5 = 0 = Signal Sound ein wird nicht gespeichert 1 = Signal Sound ein wird für die Steuerung des Schaltausgangs gespeichert, wenn CV11 = 0 ist (diese Speicherung beeinflusst nicht den Abspielmodus (CV4)) Bit 6 = 0 = Schaltausgang wirkt auf alle Sounds 1 = Schaltausgang wirkt auf die in CV24 freigegebenen Sounds Bit 7 = 0 = Signal Sound ein und Signal Sound aus wirken unabhängig von Sound aus 2⁴
| 1 = Signal Sound ein und Signal Sound aus wirken abhängig von Sound aus 2⁵ Nicht mit aktivierten LocoNET®-Interface verwendbar (CV17 Bit 0) Eine Änderung von Bit 7 wird erst nach einem Reset wirksam!
| Standard = 00010000
10 | Schaltschwelle an Analog von Lautsprecher, unterhalb derer Sound aus sofort wirkt, 0…255, Standard = 0 = keine Schaltschwelle (Sound aus sofort wirkt direkt). Wird verwendet, wenn CV6 Bit 7 nicht gesetzt und CV9 Bit 3 gesetzt sind und J3 geschlossen ist.

4 Ohne Bedeutung, wenn ein LocoNET®-Interface angeschlossen und verwendet wird.

5
„Schrankenmodus“, siehe Kapitel 5.2: Sound für den Bahnübergang (‚Schrankenmodus‘)

11 | Betriebsart für den Schaltausgang, Standard = 0: 0 = der Schaltausgang folgt dem Signal Sound ein mit Berücksichtigung von CV12, 13 und 25 (CV6 Bit 7 muss gesetzt sein, J3 ist offen) 1 = der Schaltausgang wird vom Signal Analog von Lautsprecher pegelabhängig (CV15, 16) geschaltet. (CV6 Bit 7 und CV9 Bit 3 dürfen nicht gesetzt sein, J3 ist geschlossen) 2 = Schaltausgang folgt dem Status DFPlayer aktiv 3 = Schaltausgang folgt nur dem Befehl über das LocoNET®, CV12 und CV25 werden nicht berücksichtigt. (nur sinnvoll verwendbar, wenn das LocoNET®-Interface verwendet wird)
12 | Einschaltverzögerung (in 0,1s) für Schaltausgang, 0…255, Standard = 0 = keine Zeitverzögerung Wird verwendet, wenn CV6 Bit 7 gesetzt ist und CV11=0 bzw. CV11=2 ist, J3 ist offen. CV12 wird beim Schalten über LocoNET® nicht berücksichtigt.
13 | Schaltdauer (in 0,1s) für Schaltausgang, 0…255, Standard = 0 = Dauerimpuls an Schaltausgang Wird verwendet, wenn CV6 Bit 7 gesetzt ist und CV11=0 ist, J3 ist offen.
14 | Pause (in 0,1s) zwischen dem wiederholten Abspielen des Sounds, wenn CV4 = 1, 2 oder 3 ist, Standard = 0 = keine Pause zwischen zwei Sounds
15 | Schaltschwelle an Analog von Lautsprecher, über der Schaltausgang eingeschaltet wird, 0…255, Standard = 188 Wird verwendet, wenn CV6 Bit 7 und CV9 Bit 3 nicht gesetzt sind und J3 geschlossen ist.
16 | Schaltschwelle an Analog von Lautsprecher, unter der Schaltausgang ausgeschaltet wird, 0…255, Standard = 166 Wird verwendet, wenn CV6 Bit 7 und CV9 Bit 3 nicht gesetzt sind und J3 geschlossen ist.

17 | LocoNET®-Konfiguration:
| Bit 0 = 0 = Kein LocoNET®-Interface an K4 angeschlossen
| 1 = Verwende LocoNET®-Interface an K4 (wenn vorhanden)
- J4 ist zu schließen
- Eingang Sound aus 2 ist nicht nutzbar,
| der Sound kann nur über Sound aus abgeschaltet werden
- „Schrankenmodus“ ist nicht verfügbar
| siehe Kapitel 5.2 Sound für den Bahnübergang (‚Schrankenmodus‘) Eine Änderung von Bit 0 wird erst nach einem Reset wirksam!
| Bit 1 = 0 = LocoNET®-Interface belegt eine Adresse
| 1 = LocoNET®-Interface belegt 16⁶ aufeinanderfolgende
| Adressen
- mit jeder Adresse wird ein Sound abgespielt
- erste Adresse = Sound 1, zweite Adresse = Sound 2 usw.
| Bit 2 = 0 = kein FastClockSlave - Modul angeschlossen
| 1 = FastClockSlave - Modul angeschlossen
- zum Einsatz kommt das FastClockSlave - Modul des RBM-Blockes
| Eine Änderung von Bit 2 wird erst nach einem Reset wirksam!
| Bit 3 = 1 = FastClock läuft nach Initialisierung auch intern weiter
| Bit 4 = 1 = FastClock-Telegramme von JMRI unterstützen
| Bit 5 = 1 = FastClock Phasenlage für Nebenuhr invertieren (ab
| Software Version 6)
| Bit 6 = --- Bit 7 = 0 = LocoNET®-Telegramm B0: Umschalter aktiv High
| 1 = LocoNET®-Telegramm B0: Umschalter aktiv low
| Diese Einstellung wirkt auf alle LocoNET®-Telegramme B0 Standard = 00000000 (=0)
18 | LocoNET®-Adresse für Sound ein bzw. Sound aus, 0…2048,
| Standard = 699
| Wird verwendet, wenn CV17 Bit 0 gesetzt ist.
| Für Telegramm ‚B0‘: Benennung bei LocoIO von deLoof
| (http://users.telenet.be/deloof/pageDE8.html):
| Umschalter und Ausgang Festkontakt
19 | Maximale Anzahl der verwendeten LocoNET®-Adressen für Sound ein bzw. Sound aus, siehe CV18, Standard = 1 Wird verwendet, wenn CV17 Bit 0 gesetzt ist. Maximale Anzahl insgesamt = 16
20 | Pause (in s) zwischen dem erneuten Abspielen des Sounds, wenn CV4 = 0 ist, Standard = 0 = keine Pause zwischen zwei Sounds
21 | Entprellzeit (in 10ms) für den Eingang Sound ein. Standard = 2 (20ms) Wird verwendet, wenn CV9 Bit 4 gesetzt ist. Eine Änderung von CV21 wird erst nach einem Reset wirksam!

6 Die erste LocoNET®-Adresse wird bestimmt durch CV18, die Anzahl der benötigten LocoNET®-Adressen kann durch CV20 begrenzt werden.
Beispiel für CV18 = 650:
- Adresse 650 schaltet den ersten Sound ein bzw. aus
- Adresse 651 schaltet den zweiten Sound ein bzw. aus usw.

22 | LocoNET®-Adresse für Schaltausgang ein bzw. Schaltausgang aus, 0…2048, Standard = 0 Wird verwendet, wenn CV17 Bit 0 gesetzt ist.
| Für Telegramm ‚B0‘: Benennung bei LocoIO von deLoof (http://users.telenet.be/deloof/pageDE8.html): Umschalter und Ausgang Festkontakt
23 | Ausschaltverzögerung (in 0,1s) für Schaltausgang, 0…255, Standard = 0 = keine Zeitverzögerung Wird verwendet, wenn CV6 Bit 7 gesetzt ist und CV11=0 bzw. CV11=2 ist, J3 ist offen. CV23 wird beim Schalten über LocoNET® nicht berücksichtigt.
24 | Schaltausgang wird bei den freigegebenen Sounds aktiviert (wenn CV9 Bit 6 gesetzt) Bit gesetzt heißt: Schaltausgang aktiv bei Sound-Nummer Bit 0 = Sound-Nummer 1 Bit 1 = Sound-Nummer 2 Bit 2 = Sound-Nummer 3 Bit 3 = Sound-Nummer 4 Bit 4 = Sound-Nummer 5 Bit 5 = Sound-Nummer 6 Bit 6 = Sound-Nummer 7 Bit 7 = Sound-Nummer 8 Standard = 00000000
25 | Abzuspielende Sound-Nummer, wenn der Sound gestoppt wird, 0…255, Standard = 0 = kein Sound Wird nur verwendet, wenn im Modus 0 (CV4 = 0) CV9 Bit4 gesetzt ist

Für Einschränkungen in der Verwendbarkeit der CVs siehe auch Kapitel 5.4: Sound-FRED

2.3Tabelle der CVs

(siehe: Kapitel 6: Übersicht der Einstellungen meiner AVR-Sound-Module)

2.4Inbetriebnahme mit der I²C-LCD-Anzeige- und Bedieneinheit

Nicht jeder, der ein AVR-Sound sein Eigen nennt, braucht auch eine I²C-LCD-Bedientafel – da diese aber zur Inbetriebnahme benötigt wird, sollte es wenigstens eine Bedientafel unter allen Anwendern geben…

Übrigens: diese Bedientafel wird auch zur Konfiguration des RBM-Blocks, meiner Stellwerk-Elektronik, dem LocoIO-SV-Editor und meines Intervaluino verwendet – kommt also vielfältig zum Einsatz…

Vor dem ersten Einsatz von AVR-Sound ist dieses mit Hilfe einer I²C-LCD-Anzeigeund Bedieneinheit zu konfigurieren, für den eigentlichen Betrieb ist die I²C-LCD-Anzeige- und Bedieneinheit nicht erforderlich.

Am I²C-Anschluss des AVR-Sounds kann zu jeder Zeit – auch im bereits laufenden Betrieb – die I²C-LCD-Anzeige mit Bedientastern angeschlossen bzw. entfernt werden.
Über diese Bedientafel können
- die CVs ausgelesen bzw. geändert werden,
- zahlreiche weitere Diagnosen durchgeführt werden.

Nach dem Anschließen der Bedientafel (bzw. nach dem Einschalten des AVR-Sounds mit angeschlossener Bedientafel) erscheint auf dem Display die folgende Information:

### AVR-Sound DFPlay Version 22

Durch Drücken einer beliebigen Taste gelangt man zur Auswahl der einzelnen Inbetriebnahme- bzw. Diagnosemöglichkeiten (siehe Menüstruktur).
Für die vier kreuzförmig angeordneten Auswahltasten gilt:

< beendet die aktuelle Auswahl, es wird nichts geändert bzw. gespeichert > aktiviert diese Auswahl
^ wechselt zur vorherigen Auswahl
v wechselt zur nächsten Auswahl

Die Taste OK wird für Bestätigungen oder Speicherfunktionen verwendet.

2.5Menüstruktur

AVR-Sound DFPlay
Version 22
^ | v
Status? | > | Player-Status nn | > | PortExpander 1 | > | PortExpander 2 | > | Stoerung
| < | 00000000 po xddd | < | 1111111111111111 | <¹ | 1111111111111111 | <¹ | 0000000000000000
(siehe unten) | ist kein Portexpander vorhanden, | (siehe unten)
wird „ohne“ angezeigt | 1 zurück auch mit
^ | v | < oder ^ oder v
Inbetriebnahme? | > | CV? | > | CV xx ........ | > | CV xx ........
| < | | < | y | < | >y
| | | | Anzeigemodus, mit ^ bzw. v | | Änderungsmodus², mit ^ bzw. v | | 2 bei der Änderung wird
| | | | wechselt die CV-Nummer | | wird der Wert geändert, mit OK | | mit > die Position
| | | | ........ = Kurztext | | wird der angezeigte Wert | | geändert
^ | v | geändert
| | I2C-Scan? | > | I2C-Scan
| | | < | y
Scanmodus, mit v wird die Adresse
des nächsten I²C-Teilnehmers angezeigt, am Ende der Liste wird „fertig“ ausgegeben
^ | v
Steuerung? | > | Player-Control | | | | | | In diesen Feldern sind
Änderungen / Eingaben < | >001 | möglich
| | Sound auswählen mit ^ bzw. v
| | Sound starten mit >
| | Sound stoppen mit OK
^ | v

FastClock
16:31

Je nach Ausbaustufe / angeschlossenen Erweiterungen sind nicht alle Menüpunkte sichtbar / erreichbar.

Player-Status (von links nach rechts):
- Schaltausgang von LocoNET®
- Soundmodul aktiv
- Sound ein von LocoNET®
- Status Schaltausgang, wird auch über LED D3 angezeigt
- DFPlayer aktiv, Sound wird abgespielt
Wenn OK nicht gedrückt ist:
- Eingang Sound aus 2
- Eingang Sound aus
- Eingang Sound ein
Wenn OK gedrückt ist:
- Interner Status Sound aus 2
- Interner Status Sound aus
- Interner Status Sound ein
- nn: Anzeige aktuelle Soundnummer
- | p: | Playerstatus (Ablauffolge)
- | o: | Schaltausgangstatus (Ablauffolge)
- ddd: Anzeige Wert von DIP-Switch
- | x: | s = Anzeige Wert zeigt die Sound-Nummer vom DIP-Switch an
| | l = Anzeige Wert zeigt die Lautstärke vom DIP-Switch an
| | f = Anzeige Wert zeigt die Sound-Nummer vom Sound-FRED an
| | . = Anzeige weder ‚f‘, ‚l‘ oder ‚s‘

Störung
- 000000000000000x: 0 = keine Störung
| | 1 = Zeitüberlauf beim Soundstart
| | der Sound ist nicht innerhalb von 2s gestartet.
| | Ursache kann ggf. eine nicht vorhandene Sound-Nummer sein

### 3 Hardware

Die entsprechenden Schaltbilder sind – ebenso wie die Stücklisten - im Anhang zu finden.
Die Platinen sind professionell gefertigt und haben einen beidseitigen Bestückungsaufdruck, auf Bestückungspläne und –anleitung wird daher in dieser Anleitung verzichtet.
Viele Bauteile sind in der SMD-Variante verbaut, um den Aufbau kompakt gestalten zu können. SMD-Bauteile sind in den Stücklisten farbig hervorgehoben.
Praxis für das Löten von SMD-Bauteilen sollte vorhanden sein.
Das eigentliche DFPlayer-Modul gibt es z.B. bei Amazon.

### 4 Software

Der Prozessor benötigt eine Software, um seine Aufgabe zu erfüllen.
Die Software wurde mit der Entwicklungsumgebung für die frei verfügbare Arduino-IDE (http://www.arduino.cc/) erstellt.
Die gesamte Software ist gemäß der zugehörigen Lizenz verfügbar.

4.1HEX-Dateien

Im | GitHub-Repository | befinden | sich | im | Ordner | „Hexfiles“
(https://github.com/Kruemelbahn/DFPlayer/tree/main/Hexfiles) die bereits mit dem Quellcode
kompilierten | HEX-Dateien. | Diese | Hex-Dateien | können | mit | einem | AVR-
Programmiergerät auf den Prozessor geladen werden (siehe „Den AVR flashen“). Die Namensgebung der Dateien bezeichnet die Ausbaustufe der Software:
- „SoundFred“: kennzeichnet die Verwendung für den SoundFred

4.2Quellcode

Der Quellcode im Hauptverzeichnis (https://github.com/Kruemelbahn/DFPlayer) ist genau wie meine zugehörigen Bibliotheken unter GitHub verfügbar.
Der Quellcode wird nur benötigt, wenn
- Man neugierig ist
- Oder den Quellcode ändern und somit neu kompilieren möchte. Zum Kompilieren wird die aktuelle Arduino-IDE benötigt.

Die Kompilierung erfolgt für das Board „Arduino UNO“.
Für eine erfolgreiche Kompilierung sind nachfolgende Arduino-Bibliotheken erforderlich:
Arduino-Library | | | (Link)
Adafruit-GFX-Library_master | https://github.com/adafruit/Adafruit-GFX-Library
Adafruit_LED_Backpack_Library_master | https://github.com/adafruit/Adafruit_LED_Backpack
Adafruit_RGB_LCD_Shield_Library_master | https://github.com/adafruit/Adafruit-RGB-LCD-Shield-Library
Bounce | http://www.arduino.cc/playground/Code/Bounce
Bounce2mcp | https://github.com/cosmikwolf/Bounce2mcp
DFPlayer-Mini-mp3-master | https://wiki.dfrobot.com/DFPlayer_Mini_SKU_DFR0299
LocoNET® | http://mrrwa.org/loconet-interface/
MemoryFree | http://www.arduino.cc/playground/Code/AvailableMemory
HeartBeat

LCDPanel | erfordert: Adafruit-GFX-Library
(Bibliotheken, die grün hinterlegt sind, stehen in meinem Github (http://www.github.com/Kruemelbahn) zur Verfügung.)

4.3Den AVR flashen

Hierzu kann jeder AVR-Brenner verwendet werden, der diesen Prozessor unterstützt; meine Prozessoren brenne ich mit AVRDude und USB AVR Prog von U.Radig (http://www.ulrichradig.de/).
Die Fuses sind wie folgt zu setzen: lfuse = 0xFF; hfuse = 0xDE; efuse = 0xFD

4.4Versionsgeschichte

V1 | | initiale Erstellung
V2 | | Freigabe erste Version
V3 | | neue Funktion: Sound-FRED
V4 | | Bugfix für Schaltausgang, Unterstützung Telegramm 0xF7/0xF8
V5 | neue Funktion: Statusausgang für Diagnosestecker, Anzeige Playerstatus in LCD
V6 | | FastClock: Invertierung der Phasenlage für die Nebenuhr (CV17 Bit5)
V7 | | Bugfix für PlayerControl
V8 | | Unterstützung einer 2x7Segment-Diagonse-Anzeige
V9 | | Bugfix für PlayerControl
V10 | | Bugfix in LocoNET®-Bibliothek
V11 | | Bugfix für Software-ID
V12 | | Umstellung auf OPC_PEER_XFER-Telegramme
V13 | 20.12.2020 | Bugfix für OPC_PEER_XFER-Telegramme
V14 | 18.03.2021 | Update für B0/B1/B2-Telegramme
V15 | 02.10.2021 | Abfrage S2 korrigiert (invertiert), Anpassungen für Sound-FRED
V16 | 28.06.2022 | neu: CV20 zur Begrenzung der LocoNET®-Adressen
| | neu: CV23 und CV24, um den Schaltausgang unabhängig über LocoNET®
| | steuern zu können
| | neu: CV25 Ausschaltverzögerung für den Schaltausgang
| | neu: CV26 Verknüpfung von Sound-Nummer mit Schaltausgang
| | neu: CV11 mit Betriebsart=3
V17 | 24.08.2022 | CV-Editor optimiert, CVs neu organisiert (in der Versionsgeschichte vor V17
| | benannte CVs haben sich teilweise verschoben)
V18 | 01.10.2022 | neu: CV9 Bit7 und CV25
| 16.05.2023 | redaktionelle Überarbeitungen
V19 | 21.09.2023 | geänderte Bedeutung für CV9 Bit 7: neue Betriebsart „Schrankenmodus“
| | redaktionelle Überarbeitungen
V20 | 23.10.2023 | Korrektur für FastClock-Telegramme, die von JMRI gesendet werden
| 09.12.2023 | Kapitel 4 „Software“ aktualisiert
V21 | 21.12.2023 | FastClock-Telegrammauswertung optimiert
| 23.08.2024 | Kapitel 4 ergänzt
| 03.12.2024 | Angabe zu Fuses hinzugefügt
| 17.09.2025 | Grafik in Kapitel 5.2 erweitert
| 10.10.2025 | Grafik in Kapitel 5.2 korrigiert
V22 | 06.10.2026 | CV8: Anzeige auch von MANUFACTURER- und DEVELOPER-ID,
| | JMRI-Datei angepasst

### 5 Einsatz und Verwendung

In diesem Abschnitt werden einfache Grundanwendungen für AVR-Sound skizziert, um einen ersten Eindruck der Möglichkeiten zu geben.

5.1Sound einfach

Jumper unverändert:
- J2, J6 geschlossen
- J3, J4 offen

Alle CV auf Standard – bis auf:
- CV5 = 00000000
- CV6 = 10110010

Zusatzplatinen für MOSFET-Stufe und Stecker K4/X4
können abgetrennt werden
(siehe auch Hinweis Kap. 7.1.1.)

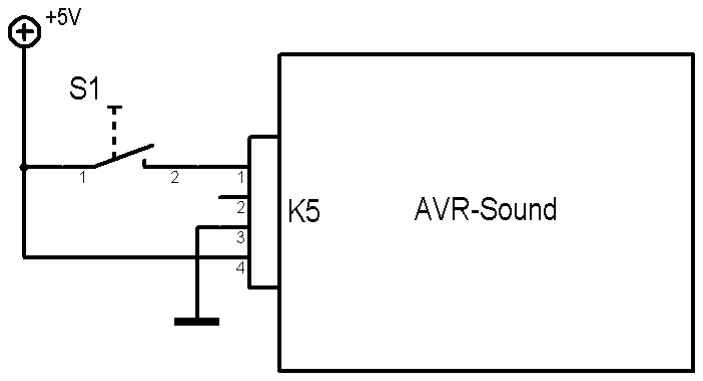
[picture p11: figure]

Einfache Soundansteuerung: der Sound wird einmalig abgespielt, wenn S1 (kurz) betätigt wird.

5.2Sound für den Bahnübergang (‚Schrankenmodus‘)

Jumper unverändert:
- J2, J6 geschlossen
- J3, J4 offen

Alle CV auf Standard – bis auf:
- CV5 = 01110011
- CV6 = 10000000

Zusatzplatine für MOSFET-Stufe kann abgetrennt werden (siehe auch Hinweis Kap. 7.1.1.)

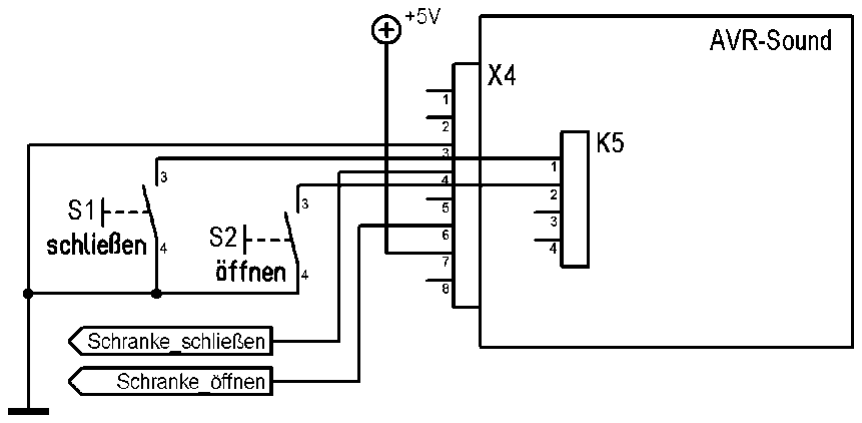
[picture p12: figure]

S1 entspricht dem Befehl „Schranke schließen“. Dieser Befehl startet den gewählten Sound und wird zeitverzögert (steuerbar über CV12) an den Ausgang (X4.4) weitergeleitet.
Ist der Schaltimpuls an S1 kürzer als die in CV12 eingestellte Zeit, kann der Impuls mit setzen von CV9 Bit 5 gespeichert („künstlich verlängert“) werden.

Über CV25 kann ein Sound definiert werden, der beim Öffnen der Schranke (z.B. über S2) abgespielt werden soll.

Mit CV9 Bit 7 = 1 kann der „Schrankenmodus“ aktiviert werden, wenn kein LocoNET®
Interface angeschlossen ist:
- dieser Modus unterdrückt die Soundausgabe, wenn:
-- die Schranke geschlossen werden soll und bereits geschlossen ist bzw. -- die Schranke geöffnet werden soll und bereits geöffnet ist
- die Schranke wird mit Sound ein geschlossen
- die Schranke wird mit Sound aus geöffnet
- der Status der Schranke (geöffnet/geschlossen) wird an Sound aus 2 angeschlossen
- CV6 Bit 0, 1 und 4 werden nicht berücksichtigt
- der Schrankenmodus kann nicht gleichzeitig mit aktivierten LocoNET®
-Interface verwendet
werden (CV17 Bit 0)

5.3Soundauswahl über den PortExpander

Jumper unverändert:
- J2, J6 geschlossen
- J3, J4 offen

Alle CV auf Standard –
bis auf:
- CV6 = 10110011
- CV9 = 00000100

Zusatzplatinen für
MOSFET-Stufe und
Stecker K4/X4 können
abgetrennt werden
(siehe auch Hinweis
Kap. 7.1.1.)

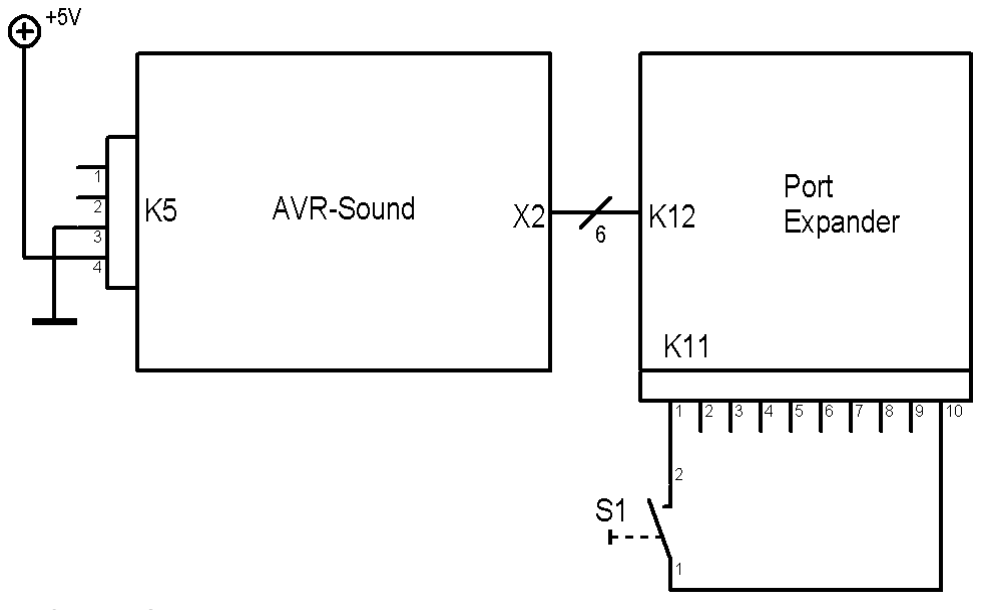
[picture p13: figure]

Einfache Soundansteuerung über den PortExpander:
- der Sound ‚0001.mp3’ wird einmalig abgespielt, wenn S1 (kurz) betätigt wird
- …
- der Sound ‚0016.mp3’ (‚0032.mp3’) wird einmalig abgespielt, wenn S16 (S32) (kurz) betätigt wird

Hinweis: Nicht verwendbar mit Sound-FRED

5.4Sound-FRED

ab SW-Version 3:

Jumper unverändert:
- J2, J6 geschlossen
- J3, J4 offen

Alle CV auf Standard – bis auf:
- CV4 = 4

Zusatzplatinen für MOSFET-Stufe und Stecker K4/X4 können abgetrennt werden (siehe auch Hinweis Kap. 7.1.1.)

Mit (kurzer) Betätigung eines der (maximal) vier Taster, die anstelle des DIP-Schalters S2 angeschlossen sind, startet der zugehörige Sound einmalig (S2.1 → ‚0001.mp3 ‘, S2.2 → ‚0002.mp3 ‘, S2.3 → ‚0003.mp3 ‘, S2.4 → ‚0004.mp3 ‘)

Für den Aufbau als Sound-FRED steht eine kleine Platine für bis zu vier Taster zur Verfügung (siehe auch Kap. 7.7.).

Den originalen Sound-FRED gibt es hier:
http://www.h0fine.de,
mögliche Sounds findet man z.B. hier: http://kleinbahnwiki.de/index.php/Sounds#Deutschland_Eisenbahnger.C3.A4usche

Mittlerweile gibt es den Sound-FRED mit angepasster Hardware auch passend für das FRED-(Handregler)-Gehäuse.
Hierfür gibt es eine angepasste Software. Dabei werden CV9 bis CV 22 nicht verwendet.

5.5Sound einfach über LocoNET®

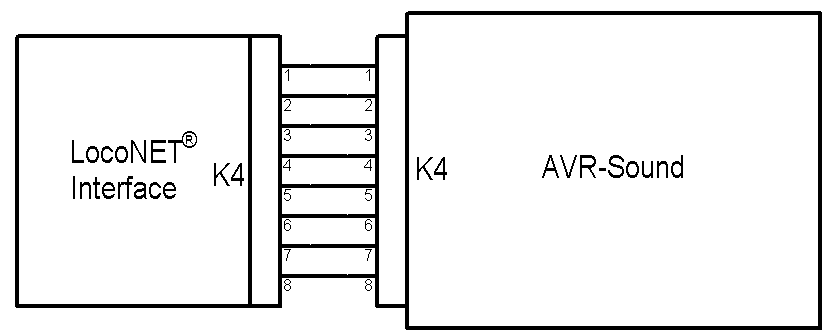
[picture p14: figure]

Jumper unverändert:
- J2, J6 geschlossen
- J3 offen
Jumper geändert:
- J4 geschlossen

Alle CV auf Standard – bis auf:
- CV6 = 10110011
- CV17 = 00000001

Zusatzplatine für MOSFET-Stufe kann abgetrennt werden (siehe auch Hinweis Kap. 7.1.1.) Einfache Soundansteuerung über LocoNET®
: der Sound wird einmalig abgespielt, wenn über ein LocoIO-Modul der Umschalter mit Adresse 699 (Standard-Adresse, kann angepasst werden) eingeschaltet wird. Für das erneute Abspielen des Sounds ist der Eingang an Adresse 699 aus- und wieder einzuschalten.

Hinweis: Der Eingang Sound aus 2 kann nicht verwendet werden, da er vom LocoNET®
Interface als LN-RX verwendet wird.

Einstellungen für Steuerelemente z.B. über LocoHDL für ein LocoIO von H. deLoof (http://users.telenet.be/deloof/pageDE8.html) am Beispiel für die Ansteuerung „Bw-E Feuerwehr“:

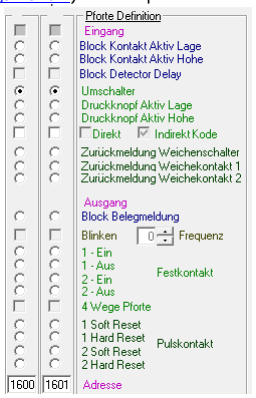
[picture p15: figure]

### 6 Übersicht der Einstellungen meiner AVR-Sound-Module

(Beschreibung der CVs: siehe Kapitel 2.2: Übersicht und Beschreibung der vorhandenen CVs)

| Stellwerk Glocke | 90°-Kurve Martinshorn | Kanalbrücke Läutewerk | Raumlicht Gewitter | Sound-FRED | Bw-E Feuerwehr
CV1 | 1 | 2 | 3 | 4 | 5 | 6
CV2 | 5 | 1 | 4 | 6…9 | 1 | 1
CV3 | 30 | 30 | 30 | 30 | 30 | 30
CV4 | 2 | 0 | 0 | 0 | 4 | 0
CV5 | 01000011 | 01000001 | 01100011 | 01000000 | 01000000 | 01000001
CV6 | 10011000 | 10010010 | 10000000 | 00011011 | 10110011 | 10010010
CV7 | 22 | 18 | 19 | 22 | 15 | 22
CV8 | 5 | 5 | 5 | 5 | 5 | 5
CV9 | 00001000 | 00000010 | 10111000 | 00000000 | 00000000 | 01100010
CV10 | 0 | 0 | 0 | 0 | 0 | 0
CV11 | 0 | 2 | 0 | 0 | 0 | 2
CV12 | 0 | 0 | 30 | 0 | 0 | 0
CV13 | 0 | 0 | 5 | 0 | 0 | 0
CV14 | 0 | 0 | 0 | 0 | 0 | 0
CV15 | 188 | 188 | 188 | 188 | 0 | 188
CV16 | 166 | 166 | 166 | 166 | 0 | 166
CV17 | 00000000 | 00000000 | 00000000 | 00000001 | 00000000 | 10000011
CV18 | 0 | 0 | 0 | 699 | 0 | 1601
CV19 | 0 | 0 | 0 | 0 | 0 | 6
CV20 | 0 | 0 | 0 | 0 | 0 | 0
CV21 | 2 | 2 | 2 | 2 | 0 | 2
CV22 | 0 | 0 | 0 | 0 | --- | 1600
CV23 | 0 | 0 | 0 | 0 | --- | 30
CV24 | 00000000 | 00000000 | 00000000 | 00000000 | --- | 00000001
CV25 | 0 | 0 | 1 | 0 | --- | 0
J1 | ☐☐ | ☐☐ | ☐☐ | ☐☐ | ☐☐ | ☐☐
J2 | ☒ | ☒ | ☒ | ☒ | ☐ | ☒
J3 | ☐ | ☐ | ☐ | ☒ | ☐ | ☐
J4 | ☐ | ☐ | ☐ | ☒ | ☐ | ☒
J6 | ☒ | ☒ | ☒ | ☒ | ☐ | ☒
R6 [Ω] | 0 | 0 | 0 | 0 | 0 | 0
Anschluss über X4 | ☐ | ☐ | ☒ | ☐ | ☐ | ☐
Anschluss über K4 | ☐ | ☐ | ☒ | ☐ | ☐ | ☐
Anschluss über K5 | ☒ | ☒ | ☐ | ☐ | ☐ | ☒
LocoNET®-an K4 | ☐ | ☐ | ☐ | ☒ | ☐ | ☒
MOSFET-Schaltstufe | ☐ | ☒ BD675 | ☐ | ☒ | ☐ | ☒ BD675
Transistor-Schaltstufe | ☐ | ☐ | ☐ | ☐ | ☐ | ☐

### 7 Anhang

7.1AVR-Sound

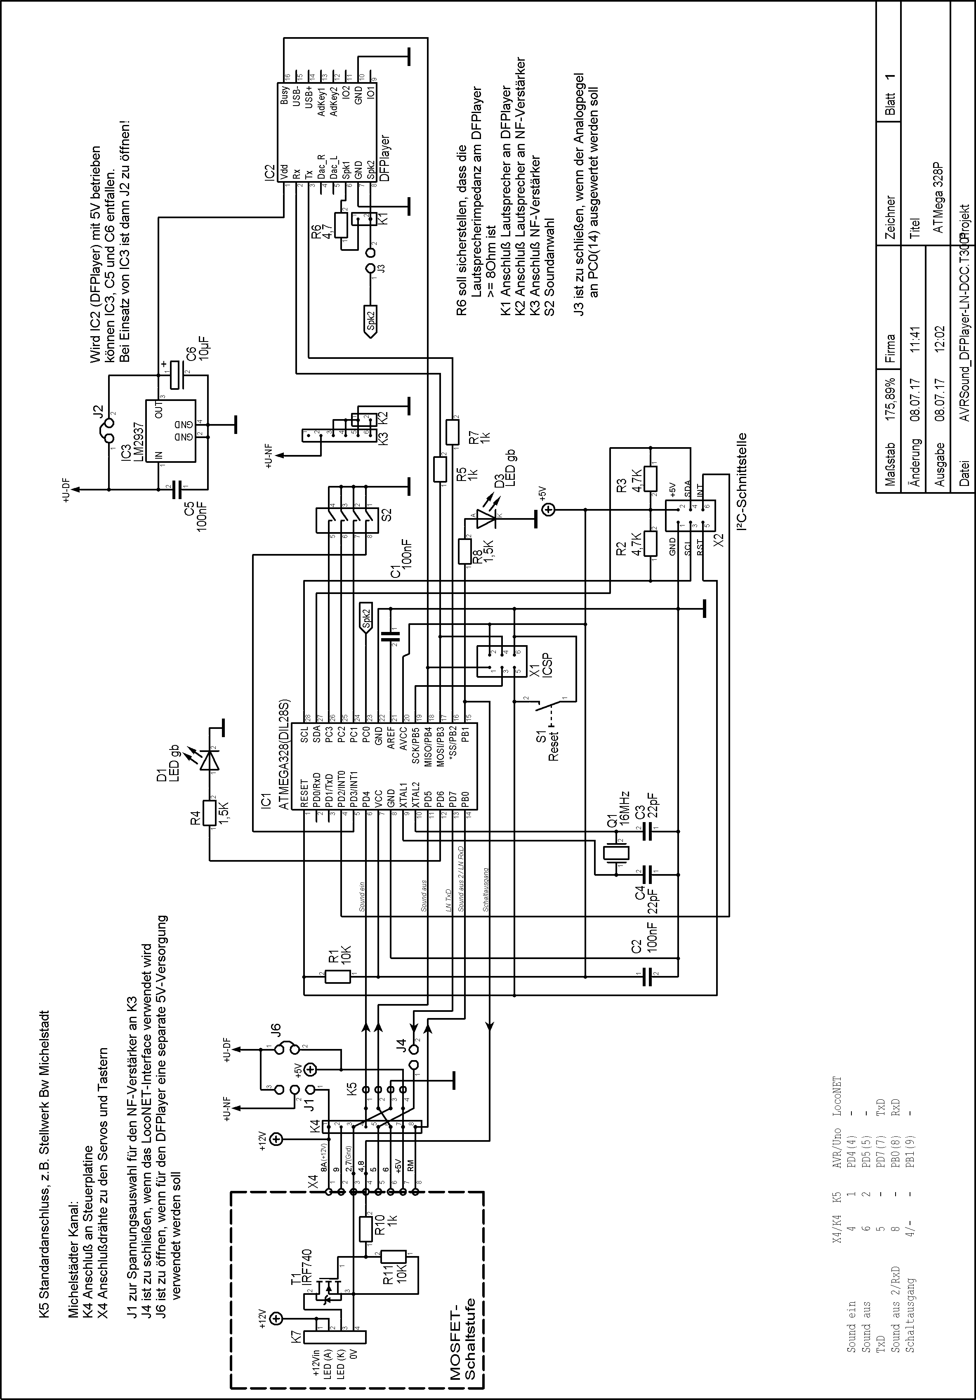
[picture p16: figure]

### 7.1.1 Stückliste AVR-Sound

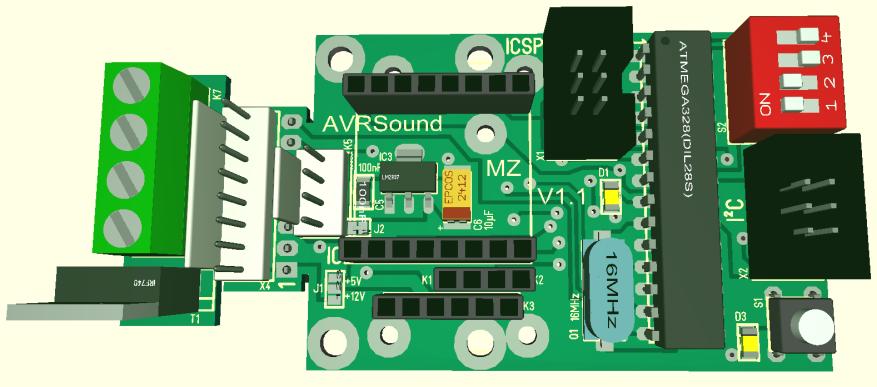
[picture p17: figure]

Anzahl | Bauteil | Bestellnummer (Reichelt⁷ ) | Anmerkung
| | | Platine 83mm * 40mm, doppelseitig, V1.1 (nur AVR-Sound: Platine 60mm * 40mm, doppelseitig, V1.1)
3 | C1, C2, C5 | X7R-G1206 100N
2 | C3, C4 | NPO-G1206 22P
1 | C6 | TAJ 6032 10/35
2 | D1, D3 | SMD-LED 1206 GE
1 | IC1 | ATMEGA 328P-PU
1 | IC1 | GS 28P-S
1 | IC2 | --- | DFPlayer Mp3-Soundmodul Der DFPlayer ist richtig positioniert, wenn der Auswurf der SD-Karte Richtung Prozessor erfolgt
1 | IC2 | --- | Micro-SD-Karte⁸ für DFPlayer
1 | IC3 | LM 2937 IMP-3.3 | IC3 wird aktuell nicht verwendet und kommt nur zur Verwendung, wenn das DFPlayer-Modul mit 3,3V werden muss (… was aktuell nicht der Fall ist…), dann ist auch J2 zu öffnen!
1 | K1, K2 | MPE 094-1-004 | K2 wird aktuell nicht verwendet
1 | K3 | MPE 094-1-006 | K3 wird aktuell nicht verwendet
3 | IC2, K4 | MPE 094-1-008
1 | K5 | PSS 254/4G
1 | K5 | PSK 254/4W
1 | Q1 | 16,0000-HC49-SMD
1 | R1 | SMD 1/4W 10K
2 | R2, R3 | SMD 1/4W 4,7K
2 | R4, R8 | SMD 1/4W 1,5K
2 | R5, R7 | SMD 1/4W 1,0K
1 | R6 | SMD 1/4W 0,0 | wenn Lautsprecherimpedanz < 8Ω ist, dann ist ein passender SMD-Widerstand zu verwenden!
1 | LS | LSM-S19K | Lautsprecher⁹ , 8Ω, 35 mm * 19 mm * 7 mm
1 | S1 | TASTER 3301
1 | S2 | NT 04
2 | X1, X2 | WSL 6G | X2 kann auch mit WSL 6W bestückt werden
1 | X4 | PSS 254/8G

7 Die in der Stückliste genannten Bestellnummern können aktuell geändert worden bzw. der Artikel nicht mehr lieferbar sein.
8 Typ der Micro-SD-Karte nach Wunsch, es ist die Spezifikation durch den DFPlayer zu beachten.

9
Für diesen Typ sind Montagebohrungen (M2) in der Platine vorhanden. Eigentlich tut es jeder Lautsprecher, es ist nur darauf zu achten, dass die Impedanz >= 8 Ω ist: hierzu ist R6 zur Anpassung zu verwenden.

1 | X4 | PSK 254/8W
1 | K5, X4 | PSK-KONTAKTE | Es werden 12 Kontakte benötigt, eine VP enthält 20 Kontakte

MOSFET-Schaltstufe

Anzahl | Bauteil | Bestellnummer (Reichelt) | Anmerkung
1 | R10 | SMD 1/4W 1K
1 | R11 | SMD 1/4W 10K
1 | T1 | IRF 740 | ggf. auch NPN-Transistor (s.u.)
1 | K7 | AKL 101-04

Hinweise zur Platine:

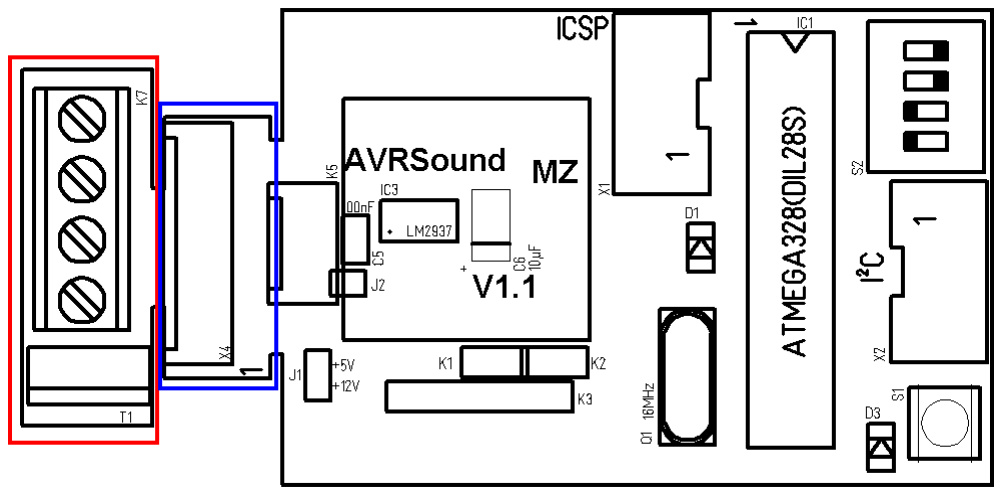
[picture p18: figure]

- Der rot umrahmte Teil enthält die MOSFET-Schaltstufe und kann – wenn diese nicht benötigt wird – entfallen/abgetrennt werden.
- Der blau umrahmte Teil enthält die Steckverbinder K4 und X4 für den Anschluss an den Michelstädter Kanal. Die Bestückung erfolgt nach Bedarf, der Platinenteil kann ggf. abgetrennt werden (dann ist die Schaltstufe auch abgetrennt und muss bei Bedarf über einzelne Drähte mit AVR-Sound verbunden werden).
- Der Lautsprecher ‚LSM-S19K‘ (Reichelt) kann mit vier M2-Schrauben direkt mit der Platine verschraubt werden (verwendet werden die 4 kleineren Bohrungen).
- Benötigtes Material: vier Schrauben M2*30 (oder länger), 12 Muttern M2 oder 4 Muttern und 4 Distanzhülsen).
- Anstelle des MOSFET IRF740 kann auch ein NPN-Transistor mit der Anschlussfolge ECB verwendet werden (Einbaurichtung beachten, Emitter Richtung K7!), z.B. BC639, BD241 oder BD675; R11 kann dann ggf. entfallen:

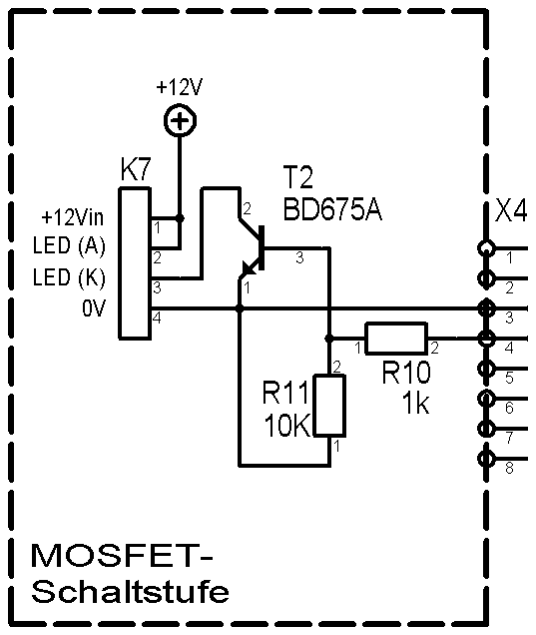
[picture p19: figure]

- Zur Bestückung: siehe auch weitere Anmerkungen/Texte im Schaltbild.

7.2LocoNET® / DCC-Interface

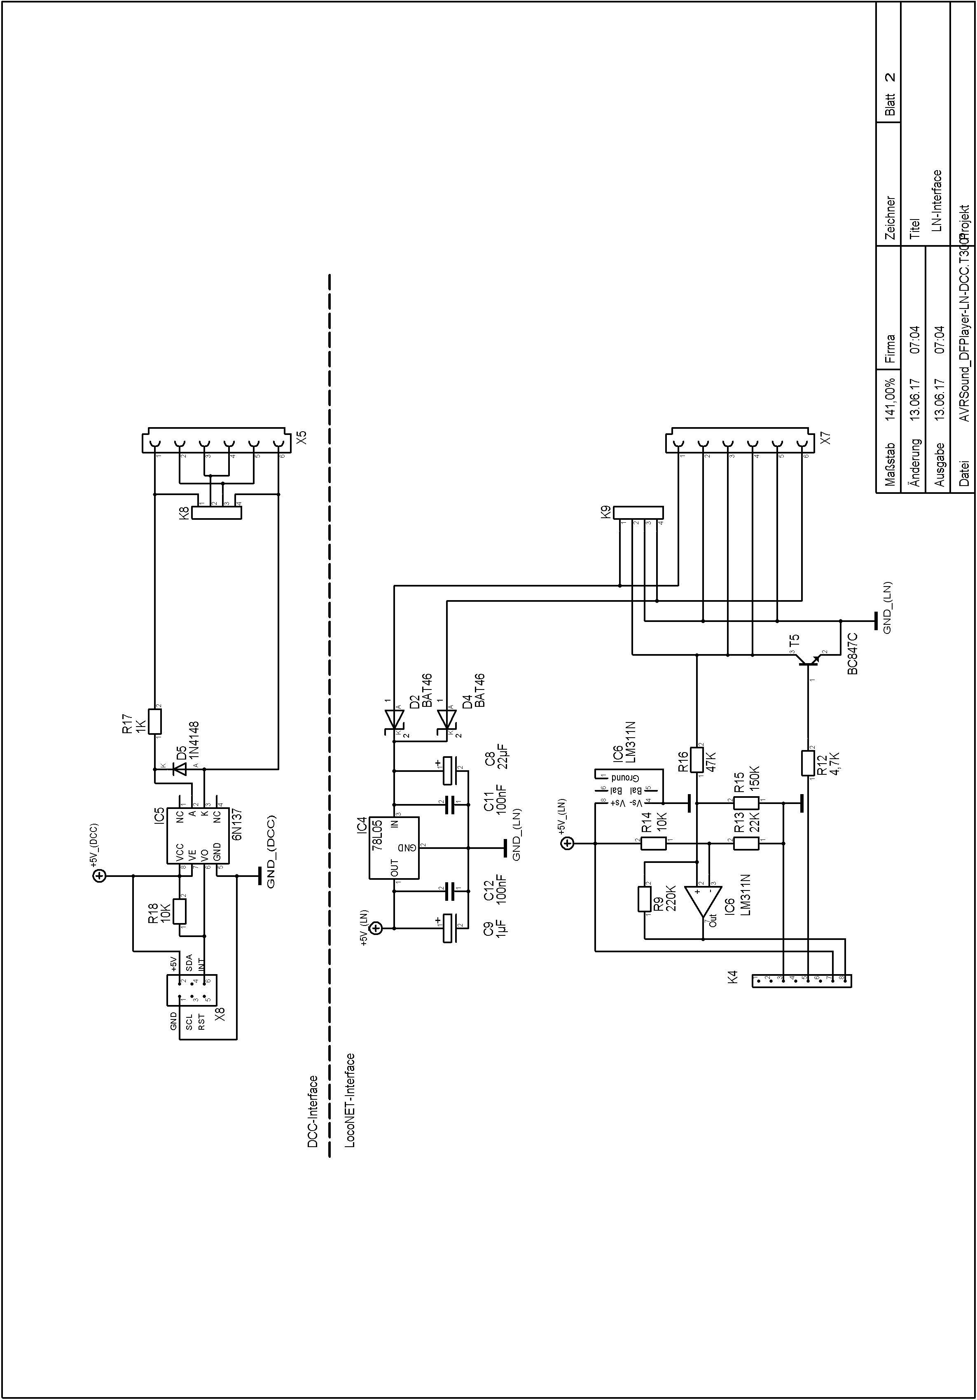
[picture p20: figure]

### 7.2.1 Stückliste LocoNET®

-Interface
Das (optionale) LocoNET®-Interface kann mit dem Soundmodul verwendet werden, hierzu ist in CV17 Bit 0 zu setzen und J4 auf dem AVR-Sound zu schließen.
Anzahl | Bauteil | Bestellnummer (Reichelt¹⁰) | Anmerkung
| | | Platine 42mm * 21mm, doppelseitig
2 | D2, D4 | BAT46 SMD | Siehe Hinweis!
2 | C11, C12 | X7R-G1206 100N | Siehe Hinweis!
1 | R9 | SMD 1/4W 220K
1 | R12 | SMD 1/4W 4,7K
1 | R13 | SMD 1/4W 22K
1 | R14 | SMD 1/4W 10K
1 | R15 | SMD 1/4W 150K
1 | R16 | SMD 1/4W 47K
1 | T5 | BC 847C SMD
1 | C8 | RAD 22/35 | RM 2,5; Siehe Hinweis!
1 | C9 | RAD 1/35
1 | IC4 | µA 78L05 | RM 2,5; Siehe Hinweis!
1 | IC6 | LM 311 DIP
1 | IC6 | GS 8P
1 | K9 | SL 1X40G 2,54 | Es werden insgesamt zwölf Stifte benötigt, die Leiste enthält 40 Stifte. Entweder wird K9 oder X7 bestückt!
1 | X7 | MEBP 6-6S | Entweder wird K9 oder X7 bestückt!
1 | K2 | WSL 6G

Hinweis:
- IC4, D2, D4, C8 und C11 dürfen nur bestückt werden, wenn AVR-Sound ausnahmsweise über das LocoNET® mit Spannung versorgt werden muss!
- Das LocoNET®-Modul kann – wenn die Stifte der Leiste K4 auf dem LocoNET®-Modul lang genug sind – von unten in die Buchse K4 des AVR-Sound-Moduls gesteckt werden – nach rechts oder nach links: je nachdem, ob die Stiftleiste von oben oder unten bestückt wurde.

10 Die in der Stückliste genannten Bestellnummern können aktuell geändert worden bzw. der Artikel nicht mehr lieferbar sein.

### 7.2.2 Stückliste DCC-Interface

Das (optionale) DCC-Interface ist eine mögliche künftige Erweiterung zur Auswertung des DCC-Signals.

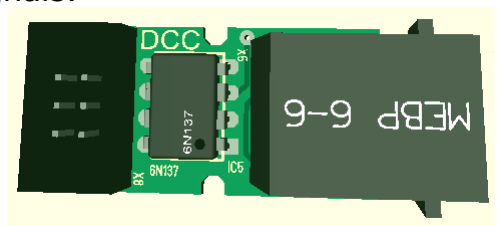
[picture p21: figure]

Anzahl | Bauteil | Bestellnummer (Reichelt¹¹) | Anmerkung
| | | Platine 34mm * 16mm, doppelseitig
1 | R17 | SMD 1/4W 1,0K
1 | R18 | SMD 1/4W 10K
1 | D5 | 1N 4148 SMD
1 | IC5 | 6N 137
1 | IC5 | GS 8P
1 | K8 | SL 1X40G 2,54 | Es werden insgesamt vier Stifte benötigt, die Leiste enthält 40 Stifte. Entweder wird K8 oder X5 bestückt!
1 | X5 | MEBP 6-6S | Entweder wird K8 oder X5 bestückt!
1 | K2 | WSL 6G

Hinweis:
- Das DCC-Modul wird über den I²C-Stecker mit AVR-Sound verbunden.

11 Die in der Stückliste genannten Bestellnummern können aktuell geändert worden bzw. der Artikel nicht mehr lieferbar sein.

7.3PortExpander

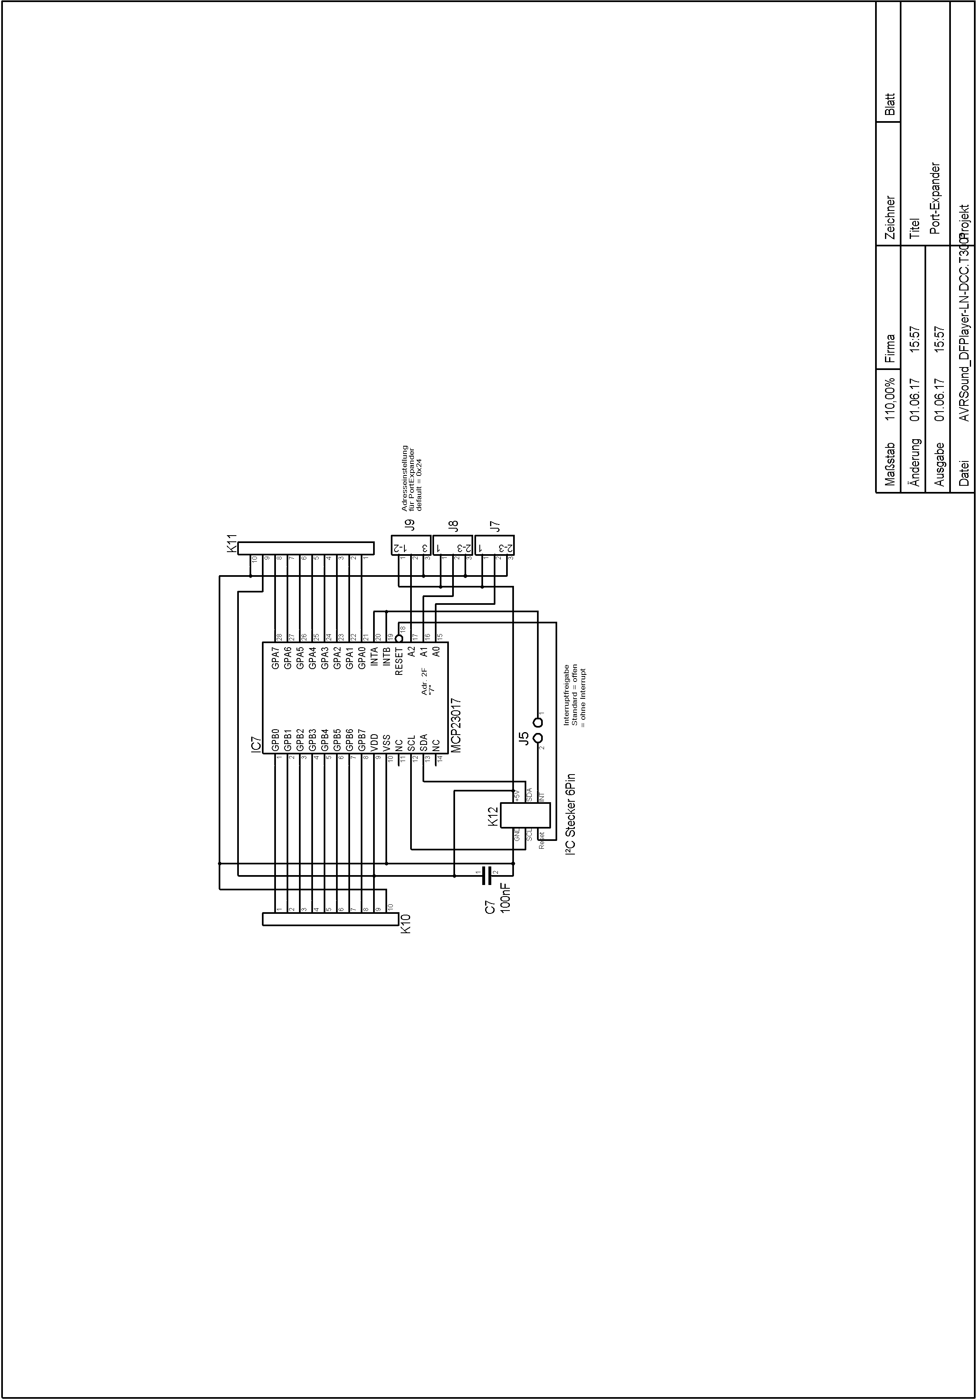
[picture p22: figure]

### 7.3.1 Stückliste PortExpander

Der (optionale) PortExpander kann mit dem Soundmodul verwendet werden, hierzu ist in CV9 Bit 2 zu setzen.

Anzahl | Bauteil | Bestellnummer (Reichelt¹²) | Anmerkung
| | | Platine 42mm * 26mm, doppelseitig
1 | C7 | X7R-G1206 100N
1 | IC7 | MCP 23017-E/SP | I²C-Adresse: 0x24 oder 0x25
1 | IC7 | GS 28P-S
2 | K10, K11 | PSS 254/10G
2 | K10, K11 | PSK 254/10W
1 | K10, K11 | PSK-KONTAKTE | Es werden 20 Kontakte benötigt, eine VP enthält 20 Kontakte
1 | K12 | WSL 6G

Die Adresse eines PortExpander wird mit J7, J8 und J9 eingestellt. Aktuell werden von AVR-Sound die Adressen 0x24 und 0x25 unterstützt.
Vor Verwendung eines PortExpander mit Adresse 0x25 ist zunächst der PortExpander mit Adresse 0x24 anzuschließen.
Adresse | J7 (A0) | J8 (A1) | J9 (A2)
0x20 | 2-3 | 2-3 | 2-3
0x21 | 1-2 | 2-3 | 2-3
0x22¹³ | 2-3 | 1-2 | 2-3
0x23 | 1-2 | 1-2 | 2-3
0x24 | 2-3 | 2-3 | 1-2
0x25 | 1-2 | 2-3 | 1-2
0x26 | 2-3 | 1-2 | 1-2
0x27 | 1-2 | 1-2 | 1-2

Der Anschluss des PortExpander an AVR-Sound kann komfortabel über Flachbandkabel erfolgen:

12 Die in der Stückliste genannten Bestellnummern können aktuell geändert worden bzw. der Artikel nicht mehr lieferbar sein.
13 Reserviert für die Statusanzeige über PortExpander

### 7.3.2 Statusanzeige über PortExpander

Mit Hilfe des Portexpanders kann an den I²C-Anschluss auch eine Statusanzeige über zwei Sieben-Segmentanzeigen realisiert werden, dabei wird links der Ausgangsstatus, rechts der Playerstatus angezeigt. Am PortExpander ist hierzu die Adresse 0x22 einzustellen.

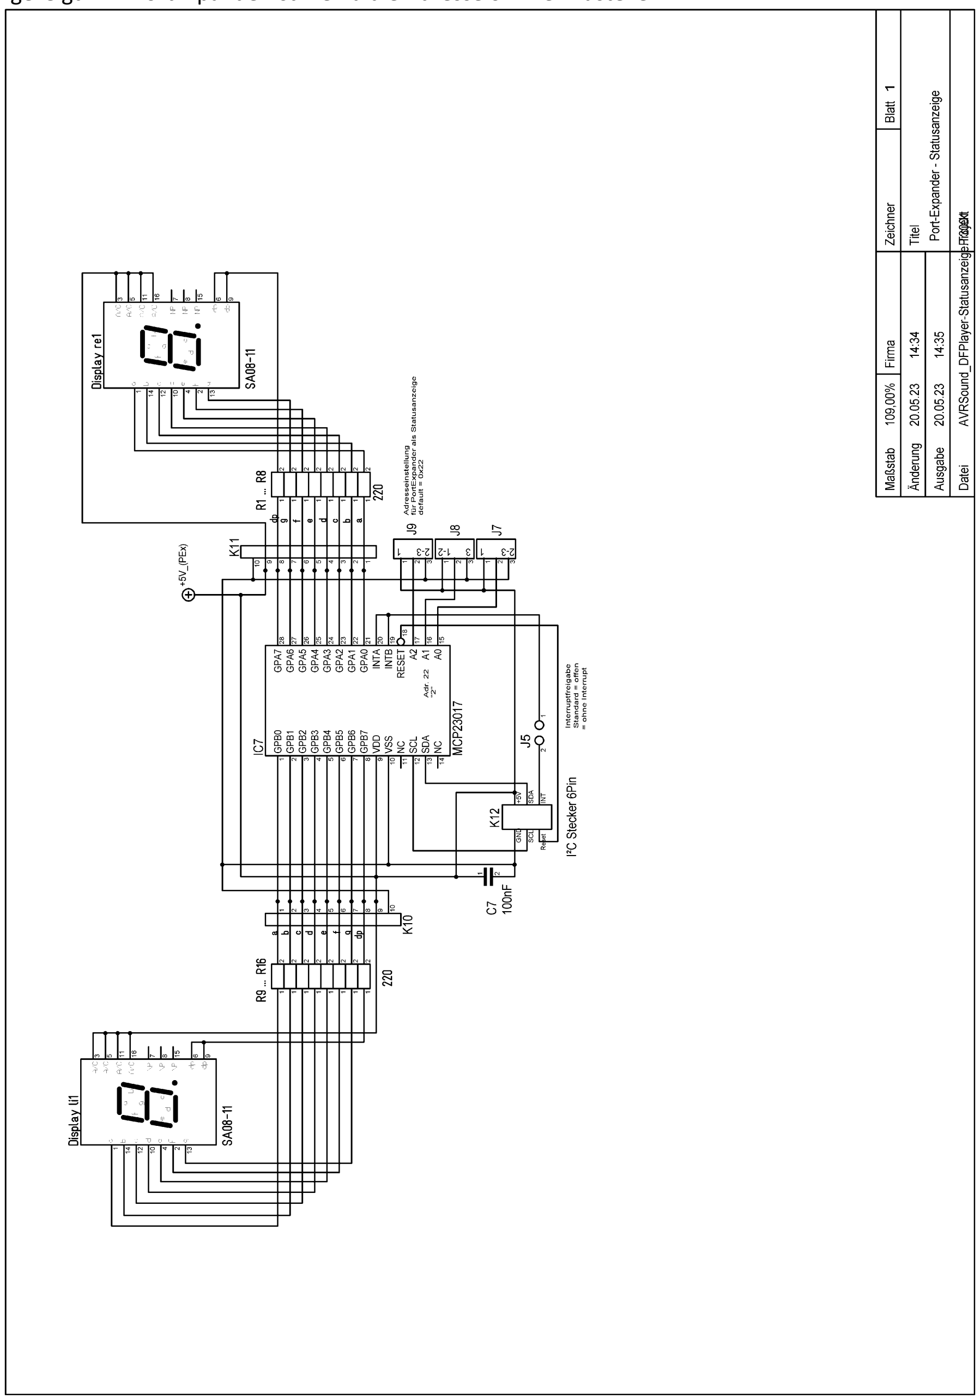
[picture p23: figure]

7.4I²C-LCD-Bedientafel

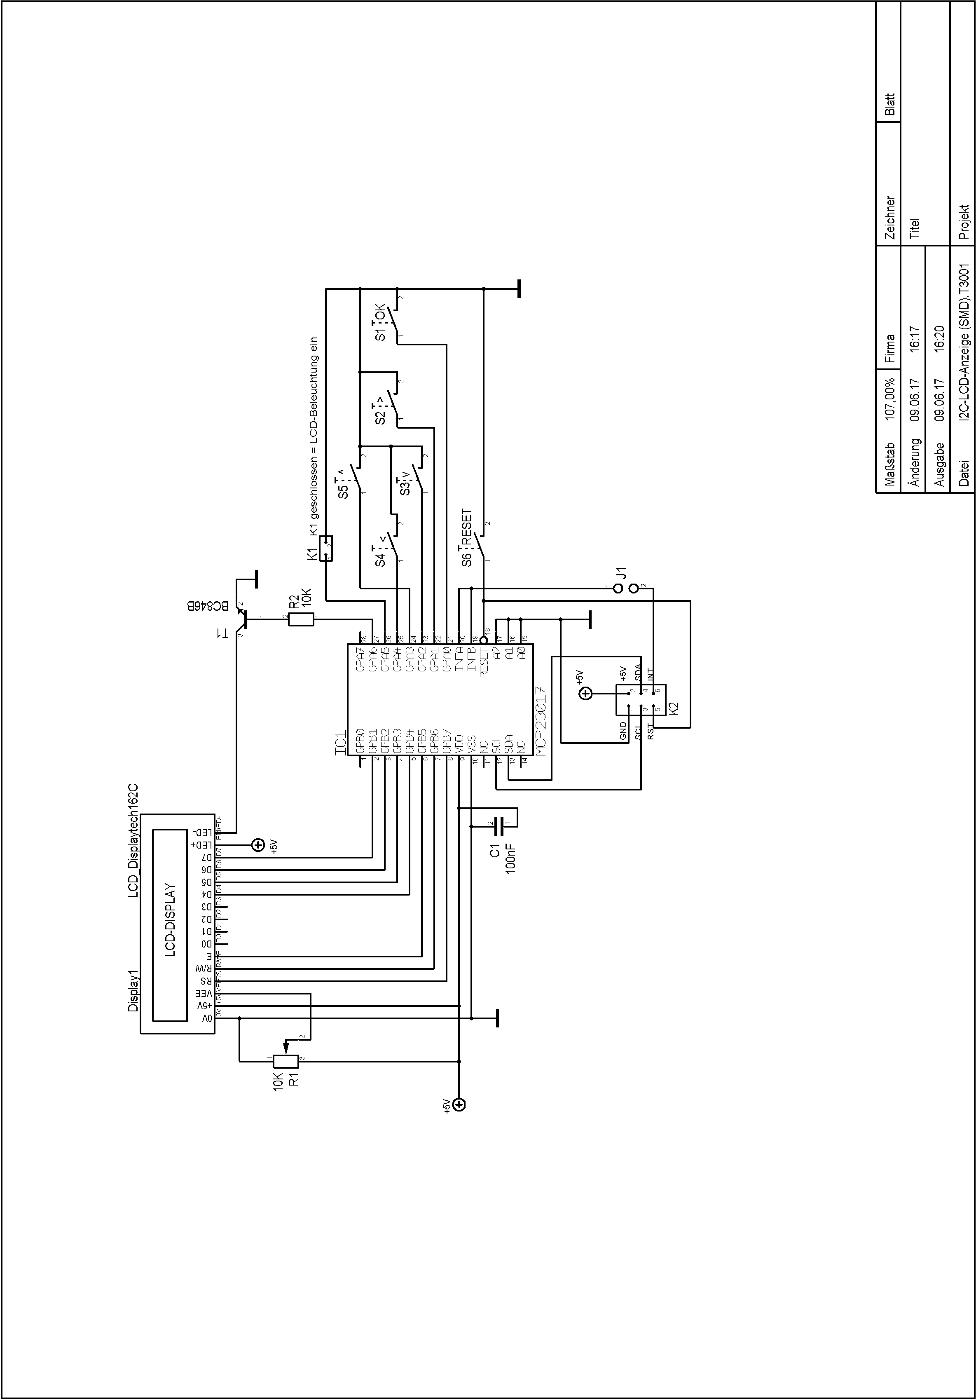
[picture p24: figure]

Die I²C-LCD-Anzeige-Einheit (optional) wird für Inbetriebnahme oder Diagnose benötigt.

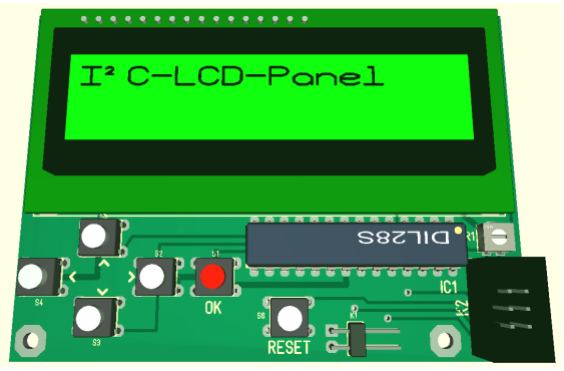
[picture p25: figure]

Die LCD-Anzeigeeinheit gibt es z.B. bei Reichelt:
http://www.reichelt.de/Erweiterungsboards/ARDUINO-SHD-LCD/3/index.html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 (http://www.reichelt.de/Erweiterungsboards/ARDUINO-SHD-LCD/3/index.html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)
(ARDUINO SHD LCD)

Einen Bausatz für die LCD-Platine (jedoch ohne LCD-Modul) gibt es hier:
https://www.exp-tech.de/module/lcd-controller/4560/adafruit-i2c/spi-character-lcd-backpack
(EXP-R15-028)

Ein passendes (HD44780-kompatibles) LCD-Modul („LCD 162C LED“) gibt es z.B. bei Reichelt:
http://www.reichelt.de/index.html?ACTION=3;ARTICLE=31653;SEARCH=LCD%20162C%20LED

### 7.4.1 Stückliste I²C-LCD-Bedientafel

Anzahl | Bauteil | Bestellnummer (Reichelt¹⁴) | Anmerkung
| | | Platine 84mm * 60mm, doppelseitig
1 | C1 | X7R-G1206 100N
1 | Display1 | LCD 162C LED | Anschluss über MPE 094-1-016 und mit SL 1X40G 2,54 sinnvoll
1 | IC1 | MCP 23017-E/SP | I²C-Adresse: 0x20
1 | IC1 | GS 28P-S
1 | K1 | SL 1X40G 2,54 | Es werden insgesamt zwei Stifte benötigt, eine Leiste enthält 40 Stifte. Auch möglich: SL 1X40W 2,54
1 | K2 | WSL 6G | Auch möglich: WSL 6W
1 | R1 | 23A-10K
1 | R2 | SMD 1/4W 10K
6 | S1…S6 | TASTER 3301 | Kurzhubtaster
1 | T1 | BC 847C SMD

14 Die in der Stückliste genannten Bestellnummern können aktuell geändert worden bzw. der Artikel nicht mehr lieferbar sein.

Hinweise:
- J1 bleibt offen
- An K1 kann ein Schalter (Schließer) zur Steuerung der LCD-Beleuchtung angeschlossen werden.
- Es wird empfohlen, das Display mit 16 Stiften aus SL 1X40G 2,54 zu bestücken, auf der Platine wird dann als Gegenstück die Buchsenleiste MPE 094-1-016 (beides nicht in der Stückliste oben enthalten) verwendet. Das Display selbst kann mit Gewindeschrauben M2 an der Platine befestigt werden und so bei Bedarf problemlos ausgetauscht werden.
- Für die Verwendung des AdaFruit-RGB-LCD-Shields (I²C-Adresse: 0x20) gilt:
- Das Shield ist zur direkten Verwendung mit einem Arduino
vorgesehen: | der | I²C-Anschluss | (K2) | ist | mit | Einzeldrähten
herzustellen (siehe die zugehörige Anleitung).
- Das Shield besitzt keinen Anschluss K1: ein Schalter bzw. Drahtbrücke ist direkt zwischen Pin 26 des MCP23017 und GND anzuschließen.

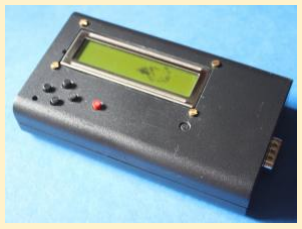
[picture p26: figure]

Meine I²C-LCD-Anzeige-Einheit habe ich in ein Gehäuse aus zwei Halbschalen (Bestellnummer bei Reichelt: SD10) mit einem seitlichen SUB-D9-Stecker für den Anschluss an den I²C-Bus montiert.

Die Anzeigeeinheit ist auf diese Art universell auch für viele weitere Anwendungen einsetzbar:
- Intervaluino
- LocoIO-SV-Editor
- LocoNET®-UhrTaktgeber
- RBM-Relaisblock
- Stellwerk
- Uhrenzentrale (Start-Stop)

Der Anschluss der I²C-Bedientafel kann komfortabel über Flachbandkabel erfolgen.

In meinem Fall habe ich den I²C-Anschluss mit einem SUB-D9-Stecker über ein Stück Flachbandkabel verbunden:

Das Anzeige-Modul ist so über den SUB-D9-Stecker an andere Geräte (siehe Kasten oben) angeschlossen werden.

7.5FastClock (Nebenuhr)

Richtig: schnelle Uhr.

Einige DCC-Zentralen sind in der Lage, eine Modellbahnuhr zu steuern und deren Zeit und Takt (eben nicht 1:1) einstellen zu können. Dieses Zeitsignal wird über ein spezielles LocoNET®-Telegramm versendet und kann ausgewertet werden.

Das von der DCC-Zentrale (leider jedoch nicht von der Frankenzentrale, hier wird ein anderes Prinzip¹⁵ verwendet) gesendete Zeitsignal kann auf unterschiedliche Arten verwendet werden:

a.) am AVR-Sound-Modul kann über den I²C-Bus ein FastClockSlave-Modul (optional, Platinengröße 64mm * 23mm) angeschlossen werden, mit der unsere Nebenuhr angesteuert werden kann. Die für die Nebenuhr erforderlichen 12V¹⁶ können auf dem Modul erzeugt werden.

AVR-Sound- Modul; I²C-Bus; FastClock-Modul; Nebenuhr

b.) Anzeige über die I²C-Bedientafel (siehe Kapitel 2.3 Inbetriebnahme mit der I²C-LCD-Bedientafel)

c.) Über ein externes (ebenfalls optionales) I²C-LED-Anzeigemodul (I²C-Adresse: 0x70), z.B. dieses: https://www.amazon.de/Adafruit-4-Ziffern-7-Segment-Display-Backpack/dp/B00DHK1E1O

d.) Aktuell kann die Verwendung von Anzeigemodulen mit einem TM1637-Chip
(z.B. | https://www.amazon.de/AZDelivery-Digital-Display-Arduino-Raspberry/dp/B06X952QXS | )
nicht unterstützt werden.

Somit ist ein Fahren nach Fahrplan auch mit einer FastClock-fähigen Zentrale (z.B. RocRail http://www.rocrail.de zusammen mit OpenDCC Z1 http://www.opendcc.de) möglich.

15 Die Frankenzentrale schaltet auf der Lokadresse 250 (diese belegt den Slot x) im eingestellten Uhrentakt abwechselnd F1 ein und aus, der aktuell verwendete Uhrendecoder OS6025 von O.Spannekrebs wertet das DCC-Signal aus.
16 Technische Daten meiner Uhr: Spannung: 12V, Innenwiderstand 1kOhm, Stromaufnahme ca. 12mA



### 7.5.1 Stückliste FastClock (Nebenuhr)

Anzahl | Bauteil | Bestellnummer (Reichelt¹⁷) | Anmerkung
| | | Platine 64mm * 23mm, doppelseitig
2 | C1,C2 | X7R-G1206 100N
1 | D1 | SMD-LED 1206 GE
1 | K1 | AKL 183-02
1 | N1 | L 272 M
1 | N1 | GS 8P
1 | N2 | PCF 8574 AT | I²C-Adresse: 0x3D Hinweis: es wird unbedingt die ‚AT‘-Version benötigt – sonst passt die I²C-Adresse nicht!
1 | N3 | SIM1-0512 SIL4 | Wandler 5V nach 12V
3 | R1…R3 | SMD 1/4W 4,7K
2 | R4,R5 | SMD 1/4W 100K
1 | R6 | SMD 1/4W 470
1 | S1 | TASTER 3301 | Kurzhubtaster
4 | V2…V5 | 1N 4148
1 | X6 | WSL 6G

Hinweise:
- FastClock wertet zur Steuerung der Nebenuhr die entsprechenden LocoNET®-Telegramme (OPC_SL_RD_DATA [0xE7] und OPC_WR_SL_DATA [0xEF]) aus und benötigt daher auch das LocoNET®-Interface
- K4 wird nicht bestückt.
- Stehen zusätzlich zur 5V-Versorgung auch 12V zur Verfügung, so kann anstelle von N3 auch eine direkte Einspeisung dieser 12V erfolgen (Anschlüsse 3 und 4 von N3). Hierbei ist zu beachten, dass die Massen (GND) von 5V und 12V zusammengeschaltet sind (gemeinsames Bezugspotential).

Inbetriebnahme
- Uhr am Wannenstecker K1 anschließen, die Uhr muss auf 12V-Betrieb stehen
- Wenn man den Taster S1 drückt, springt die Uhr auf die nächste Minute.
- Die Leuchtdiode D1 leuchtet immer bei einer ungeraden Minute.
- Sollte die Uhr anders reagieren, dann muss
- das Kabel zur Uhr gedreht angeschlossen werden oder
- die Phasenlage über CV17 Bit 4 invertiert werden

17 Die in der Stückliste genannten Bestellnummern können aktuell geändert worden bzw. der Artikel nicht mehr lieferbar sein.

7.6Transistor-Schaltstufe

Zur Potentialanpassung bei Verwendung an meiner 90°-Kurve dient mir eine zweifach-Transtorschaltstufe (die auch an anderen Stellen durchaus Verwendung finden wird, z.B. ohne R3/R4 auch als OpenCollector-Schaltstufe):


### 7.6.1 Stückliste Transistorschaltstufe

Anzahl | Bauteil | Bestellnummer (Reichelt¹⁸) | Anmerkung
| | | Platine 20mm * 15mm, doppelseitig
2 | R1,R2 | SMD 1/4W 1,0K
2 | R3, R4 | SMD 1/4W 4,7K
2 | T1, T2 | BC 846B SMD
1 | K1 | PSS 254/4G
1 | K2 | MPE 094-1-004 | Buchse wird von unten montiert und passt an K5 von AVR-Sound

18 Die in der Stückliste genannten Bestellnummern können aktuell geändert worden bzw. der Artikel nicht mehr lieferbar sein.

7.7Sound-FRED Taster


### 7.7.1 Stückliste Sound-FRED Taster

Anzahl | Bauteil | Bestellnummer (Reichelt¹⁹) | Anmerkung
| | | Platine 45mm * 14mm, einseitig
4 | S3…S6 | TASTER 3301B | Tasterhöhe nach Bedarf
1 | K13 | SL 1X40G 2,54 | Es werden insgesamt fünf Stifte benötigt, die Leiste enthält 40 Stifte. Je nach Platzbedarf kann auch eine gewinkelte Leiste verwendet werden.

Hinweise:
- S2 auf der AVR-Platine wird nicht bestückt
- K13 wird mit den Anschlüssen von S2 verbunden:
- K13.1 ist der gemeinsame Anschluss (GND) und wird an S2.1 (S2.2, S2.3 oder S2.4) angeschlossen
- K13.2 wird an S2.5 angeschlossen
- K13.3 wird an S2.6 angeschlossen
- K13.4 wird an S2.7 angeschlossen
- K13.5 wird an S2.8 angeschlossen

19 Die in der Stückliste genannten Bestellnummern können aktuell geändert worden bzw. der Artikel nicht mehr lieferbar sein.

7.8Diagnosestecker

Zur Statusanzeige (Diagnose) kann am ICSP-Anschluss ein Diagnosestecker angeschlossen werden.

Anzeige:


- Grün = Sound betriebsbereit
- Rot = Sound wird abgespielt
- Gelb = Wartezeit nach Abspielen des Sounds aktiv

### 7.8.1 Stückliste Diagnosestecker

Anzahl | Bauteil | Bestellnummer (Reichelt²⁰) | Anmerkung
| | | Platine 22mm * 16mm, doppelseitig
2 | R23, R24 | SMD 1/4W 1,0K
2 | R25, R26 | SMD 1/4W 270
2 | T4, T6 | BC 846B SMD
1 | X11 | WSL 6G
1 | D7 | LED 5RG-3

20 Die in der Stückliste genannten Bestellnummern können aktuell geändert worden bzw. der Artikel nicht mehr lieferbar sein.

7.9Kommunikation: LocoNET®-Telegramme

Die genaue Kenntnis der verwendeten Telegramme ist nur für Diagnosezwecke erforderlich und dient hier zusätzlich als Dokumentation. Weil – irgendwo muss ich das ja beschreiben…

Die Uhrenzentrale empfängt und sendet Telegramme mit den OP-Codes
- | OPC_SW_REQ | 0xB0
- | OPC_PEER_XFER | 0xE5
- | OPC_SL_RD_DATA | 0xE7 0x0E 0x7B… (FastClock-Telegramm)
- | OPC_WR_SL_DATA | 0xEF
Die Telegramme werden in der LocoNET®-Spezifikation (https://www.digitrax.com/support/loconet/loconetpersonaledition.pdf) beschrieben,
das Telegramm für OPC_PEER_XFER ist hier http://embeddedloconet.sourceforge.net/SV_Programming_Messages_v13_PE.pdf beschrieben, verwendet das „Format 2“ und folgt nicht der Empfehlung „2.2.6) Standard SV/EEPROM Locations“.

### 7.10 Übersicht: Serielle Befehle für das DFPlayer-Modul

Eine Kenntnis der seriellen Befehle für die Kommunikation mit dem DFPlayer-Modul ist nicht erforderlich und dient an dieser Stelle lediglich der Dokumentation, diese ist entnommen aus:
https://www.dfrobot.com/wiki/index.php/DFPlayer_Mini_SKU:DFR0299

Die in der Spalte "Commands" fettgedruckten Befehle werden direkt von der verwendeten Bibliothek <DFPlayer_Mini_Mp3.h> unterstützt (https://github.com/DFRobot/DFPlayer-Mini-mp3.git).

Das Handbuch zum DFPlayer-Modul gibt es hier: http://www.dfrobot.com/image/data/DFR0299/DFPlayer%20Mini%20Manul.pdf

### 7.10.1 Befehlssatz

Commands | Function Description | Parameters(16 bit)
0x01 | Next
0x02 | Previous
0x03 | Special tracking(NUM) | 0-2999
0x04 | Increase volume
0x05 | Decrease volume
0x06 | Specify volume | 0-30
0x07 | Specify EQ 0/1/2/3/4/5 | Normal/Pop/Rock/Jazz/Classic/Bass
0x08 | Specify playback mode(0/1/2/3) | repeat/folder repeat/single repeat/random
0x09 | Specify playback source( 0/1/2/3/4) | U/TF/AUX/SLEEP/FLASH
0x0A | Enter into standby-low power loss
0x0B | Normal working
0x0C | Reset module
0x0D | Playback
0x0E | Pause
0x0F | Specify folder to playback | 1-10（need to set by user）
0x10 | Volume adjust set | [DH=1:Open volume adjust][DL:set volume gain 0-31]
0x11 | Repeat play | [1:start repeat play][0:stop play]
0x12 | Specify MP3 tracks folder | 0-9999
0x13 | Commercials | 0-9999
0x14 | Support 15 folder | See detailed description
0x15 | Stop playback, play background
0x16 | Stop playback
0x17 | ??
0x18 | ?Random?
0x19 | ?single play?
0x1A | ?DAC?

### 7.10.2 Abfragebefehle

Commands | Function Description | Parameters(16bit)
0x3C | STAY
0x3D | STAY
0x3E | STAY
0x3F | Send initialization parameters | 0-0x0F（each bit represent one device of the low-four bits）
0x40 | Returns an error, request retransmission
0x41 | Reply
0x42 | Query the current status
0x43 | Query the current volume
0x44 | Query the current status EQ
0x45 | Query the current playback mode | This version retains this feature
0x46 | Query the current software version | This version retains this feature
0x47 | Query the total number of TF card files
0x48 | Query the total number of U-disk files
0x49 | Query the total number of FLASH card files
0x4A | keep on
0x4B | Queries the current track of TF card
0x4C | Queries the current track of U-disk
0x4D | Queries the current track of Flash

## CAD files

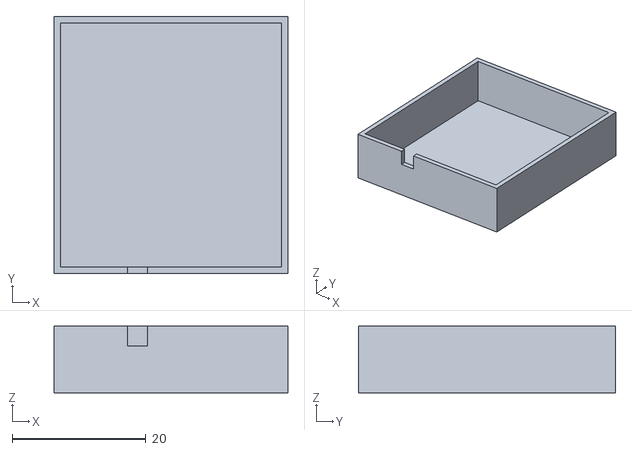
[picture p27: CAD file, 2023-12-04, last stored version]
Akkuschale-SoundFred.stl
35.0 x 38.5 x 10.0

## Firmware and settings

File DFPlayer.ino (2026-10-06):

/*
 * DFPlayer
 
used I²C-Addresses:
  - 0x20 LCD-Panel (optional)
  - 0x22 7Seg-Status-Display (optional)
  - 0x24 first PortExpander (optional)
  - 0x25 second PortExpander (optional)
  - 0x3D FastClock-Interface
  - 0x70 FastClock-LED-Display
  
discrete In/Outs used for functionalities:
  -  0     (used  USB)
  -  1     (used  USB)
  -  2 In  (used  I²C-Interrupt, DCC-In)
  -  3 In   used  Selector S2.0
	-  4 In   used  start sound
  -  5 In   used  stop sound immediatly
  -  6 Out  used  by HeartBeat / Stoerung
  -  7 Out (used              LocoNet [TxD]) 
  -  8 In   used  stop sound (LocoNet [TxD])
  -  9 Out  used  switch     (LocoNet [CTS])
  - 10 In   used  Player [RxD]    [SS]   (used  by ETH-Shield for W1500-select)
  - 11 Out  used  Player [TxD]    [MOSI] (used  by ETH-Shield) 
  - 12 In   used  Player busy     [MISO] (used  by ETH-Shield) 
  - 13 Out  used  Player state    [SCK]  (used  by ETH-Shield) 
  - 14 In   used  Player-Level (Speaker-Signal)
  - 15 In   used  Selector S2.1
  - 16 In   used  Selector S2.2
  - 17 In   used  Selector S2.3
  - 18     (used by I²C: SDA)
  - 19     (used by I²C: SCL)

 *************************************************** 
 *  Copyright (c) 2018 Michael Zimmermann <http://www.kruemelsoft.privat.t-online.de>
 *  All rights reserved.
 *
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
 ****************************************************
 */

//=== global stuff =======================================
//#define DEBUG 1   // enables Outputs (debugging informations) to Serial monitor (needs ~1k of code)
                  // note: activating SerialMonitor in Arduino-IDE
                  //       will create a reset in software on board!
                  // please comment out also includes in system.ino

//#define DEBUG_CV 1 // enables CV-Output to serial port during program start (saves 180Bytes of code :-)
//#define DEBUG_MEM 1 // enables memory status on serial port (saves 350Bytes of code :-)

//#define ETHERNET_BOARD 1  // needs ~11.5k of code, ~180Bytes of RAM
//#define ETHERNET_WITH_LOCOIO 1
//#define ETHERNET_PAGE_SERVER 1

//#define FAST_CLOCK_LOCAL  //use local ports for slave clock if no I2C-clock is found.

//=============================================
// if activated, the software can only be used for Sound-FRED without other possibilitys such as LN, Start stop etc.
//#define _SPECIAL_SOUND_FRED_	

#if defined _SPECIAL_SOUND_FRED_
	#if F_CPU != 8000000
	  #error "Invalid clock speed - must be 8MHz"  
  #endif
#else
	#if F_CPU != 16000000
	  #error "Invalid clock speed - must be 16MHz"  
  #endif
#endif
//=============================================

#define LCD     // used in GlobalOutPrint.ino

#include "CV.h"

// more definitions are made in PlayerControl
#define ENABLE_SOUND_FROM_S2  (GetCV(ADD_FUNCTIONS_1) & 0x01)
#define ENABLE_LEVEL_FROM_S2  (GetCV(ADD_FUNCTIONS_1) & 0x02)
#define ENABLE_LN             (GetCV(LN_FUNCTIONS) & 0x01)
#define ENABLE_LN_E5          (1)
#define ENABLE_LN_16          (GetCV(LN_FUNCTIONS) & 0x02)
#define ENABLE_LN_FC_MODUL    (GetCV(LN_FUNCTIONS) & 0x04)
#define ENABLE_LN_FC_INTERN   (GetCV(LN_FUNCTIONS) & 0x08)
#define ENABLE_LN_FC_INVERT   (GetCV(LN_FUNCTIONS) & 0x20)
#define ENABLE_LN_FC_SLAVE    (ENABLE_LN_FC_MODUL)
#define ENABLE_LN_FC_MASTER   (0)
#define ENABLE_LN_SW_INVERT   (GetCV(LN_FUNCTIONS) & 0x80)
#define ENABLE_LN_FC_JMRI     (GetCV(LN_FUNCTIONS) & 0x10)

#define UNREFERENCED_PARAMETER(P) { (P) = (P); }

#define MANUFACTURER_ID  13   // NMRA: DIY
#define DEVELOPER_ID  29      // NMRA: my ID, (1 = FREMO, see https://groups.io/g/LocoNet-Hackers/files/LocoNet%20Hackers%20DeveloperId%20List_v29.html)

//=============================================

#include <LocoNet.h>  // requested for notifySwitchRequest, notifyFastClock

#include <HeartBeat.h>
HeartBeat oHeartbeat;

//========================================================
void setup()
{
#if defined DEBUG
  // initialize serial and wait for port to open:
  Serial.begin(57600);
#endif

  ReadCVsFromEEPROM();
  
  InitLocoNet();

  InitFastClock();

  CheckAndInitLCDPanel();

  CheckAndInitPlayer();

#if defined ETHERNET_BOARD
  InitEthernet();
#endif
}

void loop()
{
  // generate blinken
  Blinken();

  if(!GetStoerung())
    // light the Heartbeat LED
    oHeartbeat.beat();
  else
    // flash heartbeat-led for disturbance:
    digitalWrite(6, Blinken2Hz());
        
  //=== do LCD handling ==============
  // can be connected every time
  // panel only necessary for setup CV's (or some status informations):
  HandleLCDPanel();
  
  //=== do LocoNet handling ==========
  HandleLocoNetMessages();

  //=== do FastClock handling ==========
  HandleFastClock();

  //=== do Player handling =======
  HandlePlayer();

  //=== do diagnostic handling =======
  CheckAndInit2x7SegmentPanel(true);
  outToDisplay1(GetPlayState(), GetPlayerStatus() & 0x08 ? true : false); // PlayerBusy
  outToDisplay2(GetOutState(), GetPlayerStatus() & 0x10 ? true : false);  // OutputState

#if defined ETHERNET_BOARD
  //=== react on Ethernet requests ===
  HandleEthernetRequests();
#endif
  
#if defined DEBUG
  #if defined DEBUG_MEM
    ViewFreeMemory();  // shows memory usage
    ShowTimeDiff();    // shows time for 1 cycle
  #endif
#endif
}

//=== will be called from LocoNet-Class
// Address: 	Switch Address.
// Output: 		Value 0 for Coil Off, 0x10 for Coil On
// Direction: Value 0 for Thrown/RED, 0x20 for Closed/GREEN
void notifySwitchRequest(uint16_t Address, uint8_t Output, uint8_t Direction)
{ // OPC_SW_REQ (B0) received:
#if defined DEBUG || defined TELEGRAM_FROM_SERIAL
  Printout('R');
  PrintAdr(Address);
#endif
  if (Output)
  {
		boolean b_SoundFromLN(Direction ? true : false);  // "Grün" oder "Rot"
    if (ENABLE_LN_SW_INVERT)
      b_SoundFromLN = (Direction ? false : true);  // "Rot oder "Grün"

    uint16_t ui16AdrOn(readAddressFromSound_OnOff());
    if (ui16AdrOn && Address == ui16AdrOn)
      SetSoundStatusFromLN(b_SoundFromLN, 0);
    if (ENABLE_LN_16)
    {
      uint8_t ui8LnMaxAdrCnt(GetCV(LN_MAX_ADRCNT));
      if (ui8LnMaxAdrCnt && ui16AdrOn && (Address >= ui16AdrOn) && (Address < (ui16AdrOn + ui8LnMaxAdrCnt)))
        SetSoundStatusFromLN(b_SoundFromLN, Address - ui16AdrOn + 1);
    } // if(ENABLE_LN_16)

    uint16_t ui16AdrSwOn(readAddressFromSwitchOutput_OnOff());
    if (ui16AdrSwOn && Address == ui16AdrSwOn)
      SetSwitchOutputStatusFromLN(b_SoundFromLN);
  } // if (Output)
}

/*=== will be called from LocoNetFastClockClass
			if telegram is OPC_SL_RD_DATA [0xE7] or OPC_WR_SL_DATA [0xEF] and clk-state != IDLE ==================*/
void notifyFastClock( uint8_t Rate, uint8_t Day, uint8_t Hour, uint8_t Minute, uint8_t Sync )
{
#if defined DEBUG
  Serial.print(F("notifyFastClock "));
  Serial.print(Hour);
  Serial.print(":");
  decout(Serial, Minute, 2);
  Serial.print("[Rate=");
  Serial.print(Rate);
  Serial.print("][Sync=");
  Serial.print(Sync);
	Serial.println("]");
#endif    
  SetFastClock(Rate, Day, Hour, Minute, Sync);
}

void notifyFastClockFracMins(uint16_t FracMins)
{
  HandleFracMins(FracMins);
}

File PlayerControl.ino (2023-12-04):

//=== PlayerControl for DFPlayer ===
#include <SoftwareSerial.h>
#include <DFPlayer_Mini_Mp3.h>
#include <Wire.h>
#include <Adafruit_RGBLCDShield.h>
#include <Bounce.h>

/* description of In's and Out's
  -  0     (used  USB)
  -  1     (used  USB)
  -  2 In  (used  I²C-Interrupt, DCC-In)
  -  3 In   used  Selector S2.0
  -  4 In   used  start sound     [CS]   (used  by ETH-Shield for SD-Card-select, Remark: memory using SD = 4862 Flash, 791 RAM))
  -  5 In   used  stop sound immediatly
  -  6 Out  used  by HeartBeat
  -  7 Out (used              LocoNet [TxD]) 
  -  8 In   used  stop sound (LocoNet [TxD])
  -  9 Out  used  switch     (LocoNet [CTS])
  - 10 In   used  Player [RxD]    [SS]   (used  by ETH-Shield for W1500-select)
  - 11 Out  used  Player [TxD]    [MOSI] (used  by ETH-Shield) 
  - 12 In   used  Player busy     [MISO] (used  by ETH-Shield) 
  - 13 Out  used  Player state    [SCK]  (used  by ETH-Shield) 
  - 14 In   used  Player-Level (Speaker-Signal)
  - 15 In   used  Selector S2.1
  - 16 In   used  Selector S2.2
  - 17 In   used  Selector S2.3
*/

#define SOUND_START     4
#define SOUND_STOP      5
#define SOUND_STOP_2    8
#define SWITCH_OUT      9

#define PLAYER_RXD     10
#define PLAYER_TXD     11
#define PLAYER_BUSY    12
#define PLAYER_STATE   13
#define PLAYER_LEVEL   14
#define SENSOR_IN       0    // A0

#define S2_0            3
#define S2_1           15
#define S2_2           16
#define S2_3           17

// more definitions are made in DFPlayer
#define ENABLE_PORTEXPANDER   	(GetCV(ADD_FUNCTIONS_1) & 0x04)
#define ENABLE_OFF_IMMEDIATLY 	(GetCV(ADD_FUNCTIONS_1) & 0x08)
#define ENABLE_KEEP_STATE     	(GetCV(ADD_FUNCTIONS_1) & 0x20)
#define ENABLE_SWITCH_AND_SNDNO (GetCV(ADD_FUNCTIONS_1) & 0x40)
#define ENABLE_BARRIER_MODE     (GetCV(ADD_FUNCTIONS_1) & 0x80)

//=== declaration of var's =======================================
/*
 * ETH-Shield uses Arduino-pins: 10, 11, 12, 13
 * therefor we comment out all functions used by DFPlayer 
 *   (e.g. SoftwareSerial, mp3_set_serial, mp3_stop, mp3_play, mp3_set_volume)
 */
#if not defined ETHERNET_BOARD
  SoftwareSerial playerSerial(PLAYER_RXD, PLAYER_TXD); // RX, TX
#endif

#define PORT_EXPANDER_ADDRESS   0x24  //  16E
#define PORT_EXPANDER_ADDRESS_2 0x25  //  16E
Adafruit_MCP23017 portsIn_24 = Adafruit_MCP23017();
Adafruit_MCP23017 portsIn_25 = Adafruit_MCP23017();

// instanciate Bounce-Object for 20ms
Bounce bouncerSoundStart = Bounce(SOUND_START, 20);
Bounce bouncerSoundStop = Bounce(SOUND_STOP, 20);

boolean b_PortExpander_24_present = false;
boolean b_PortExpander_25_present = false;
uint16_t ui16_InPortExpander_24 = 0;
uint16_t ui16_InPortExpander_25 = 0;

uint16_t ui16_Stoerung = 0;

boolean b_SoundStart = false;
boolean b_SoundStop = false;
boolean b_SoundStop2 = false;
boolean b_PlayerBusy = false;
boolean b_PlayerBusyMirror = false;
boolean b_OutputState = false;

boolean b_SoundFromLN = false;
boolean b_SwitchOutputFromLN = false;
uint8_t ui8_SoundNoFromLN = 0;
boolean b_keepPlayingMode3 = false;
boolean b_keepSoundState = false;
boolean b_SwitchStateOffDelay = false;

boolean b_SoundFred = false;

boolean b_PlayerState = false;

uint8_t ui8_ValueFromDIPSwitch = 0;
uint8_t ui8_SoundNoFromPortExpander = 0;
uint8_t ui8_SoundNoFromStop = 0;
uint8_t ui8_PlayerState = 0;
uint8_t ui8_OutputStateMode0 = 0;
uint8_t ui8_OutputStateMode2 = 0;
uint8_t ui8_CurrentSoundPlaying = 0;

#if defined DEBUG
uint8_t ui8_PlayerStateMirror = UINT8_MAX;
uint8_t ui8_OutputStateMode0Mirror = UINT8_MAX;
#endif

unsigned long ul_StartSoundDelay = 0;
unsigned long ul_SoundMillisPause = 0;
unsigned long ul_SoundMillisWait = 0;
unsigned long ul_OutputMillisDelayON = 0;
unsigned long ul_OutputMillisDelayOFF = 0;
unsigned long ul_OutputMillisPulse = 0;

//=== functions ==================================================
void    SetSoundStatusFromLN(boolean bState, uint8_t ui8_SndNo)
{ 
	b_SoundFromLN = bState; 
  if (b_SoundFromLN)  // "Grün" oder "Rot"
    stopSound();  		// stop any playing sound before starting a new one...
	ui8_SoundNoFromLN = ui8_SndNo;
}

void    SetSwitchOutputStatusFromLN(boolean bState) { b_SwitchOutputFromLN = bState; }

uint8_t GetPlayerStatus()
{ 
  uint8_t bReturn(b_PlayerBusy << 3 | b_OutputState << 4 | b_SoundFromLN << 5 | b_PlayerState << 6 | b_SwitchOutputFromLN << 7);
  if(isButtonOKPressed())
    bReturn |= (b_SoundStart | b_SoundStop << 1 | b_SoundStop2 << 2);
  else
    bReturn |= (digitalRead(SOUND_START) | digitalRead(SOUND_STOP) << 1 | digitalRead(SOUND_STOP_2) << 2);
  return bReturn;
}

uint8_t GetValueFromDIPSwitch() { return ui8_ValueFromDIPSwitch; }
uint8_t GetCurrentSoundPlaying() { return ui8_CurrentSoundPlaying; }

uint8_t GetPlayState() { return ui8_PlayerState; }
uint8_t GetOutState()
{ 
  uint8_t ui8_SwitchMode(GetCV(PIN5_MODUS));
  if(ui8_SwitchMode == 0)
    return ui8_OutputStateMode0;
  if (ui8_SwitchMode == 2)
    return ui8_OutputStateMode2;
  return 0;
}

boolean IsSoundFred() { return b_SoundFred; }

uint16_t GetStoerung() { return ui16_Stoerung; }

uint16_t GetPortExpander_24() { return ui16_InPortExpander_24; }
uint16_t GetPortExpander_25() { return ui16_InPortExpander_25; }
boolean IsPortExpanderPresent_24() { return b_PortExpander_24_present; }
boolean IsPortExpanderPresent_25() { return b_PortExpander_25_present; }
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

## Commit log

2023-12-04 Added files for V20.0
    [Akkuschale-SoundFred.stl]
2024-01-18 repository structure changed
    [Akkuschale-SoundFred.stl]
2024-12-02 Cleaning up the repository
    [Akkuschale-SoundFred.stl]
2024-12-03 Information fpr fuses in documentation added
